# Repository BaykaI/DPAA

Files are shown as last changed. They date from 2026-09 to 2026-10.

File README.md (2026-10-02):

# DPAA — ЦАФАР, которую можно услышать

Проект демонстрации принципов **цифровой активной фазированной антенной решётки
(ЦАФАР)** в акустическом диапазоне: вместо антенн — динамики и микрофоны, вместо
СВЧ — звук 1.5–4 кГц, вместо осциллографа — уши зрителей.

Звук в ~875 000 раз медленнее радиоволн, поэтому решётка из восьми динамиков
с шагом 4 см геометрически эквивалентна решётке S-диапазона, а обычная
многоканальная звуковая карта оцифровывает сигнал прямо на «несущей» — то, о чём
мечтают разработчики настоящих ЦАФАР.

Подробная концепция, расчёты, сценарии и варианты железа: **[docs/concept.md](docs/concept.md)**.

**Железо** (16 элементов, ПЛИС ECP5 на модуле Colorlight i9, ≈ 630 $, с резервом ≈ 725 $ из 1000 $):
[архитектура](docs/hardware/architecture.md) · [что купить и заказать](docs/hardware/purchase.md) · [спецификация и бюджет](docs/hardware/bom.md) ·
[схемы плат](docs/hardware/schematics.md) · [распиновка](docs/hardware/pinout.md) ·
[схема соединений](docs/hardware/wiring.md) · [полная структурная схема](docs/img/full_diagram.svg) · [элемент: динамик + микрофон, 3D-модель](docs/hardware/mechanics.md) ·
[прошивка ПЛИС](gateware/README.md)

Структурная схема установки

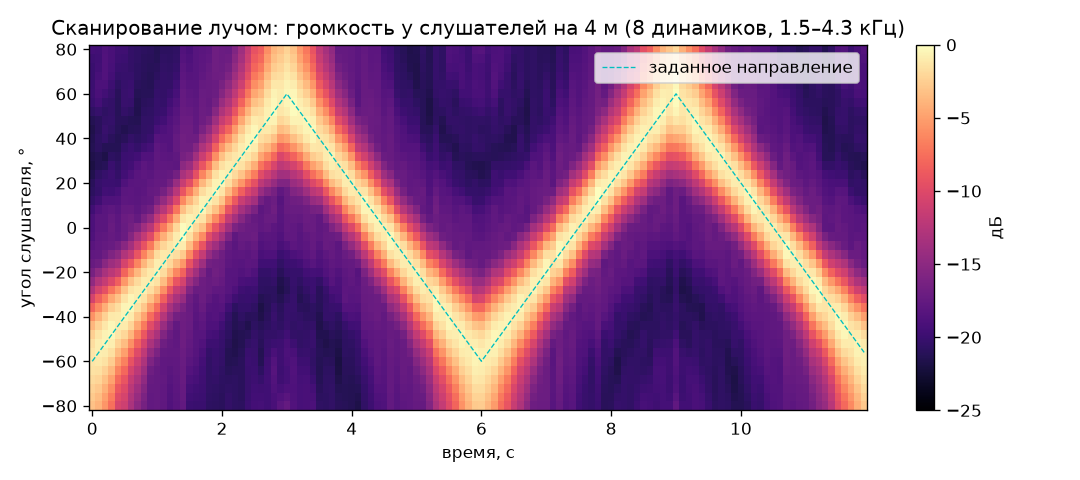
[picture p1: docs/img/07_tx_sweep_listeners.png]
Сканирование лучом


## Что уже есть

* `dpaa/` — небольшая библиотека моделирования:
  * `geometry.py` — решётки (линейные, плоские), направления, задержки фазирования;
  * `signals.py` — дробные задержки (БПФ и КИХ для реального времени), фазовращатель,
    тестовые сигналы;
  * `patterns.py` — диаграммы направленности, весовые окна, «косоглазие» луча, квантование;
  * `propagation.py` — распространение звука в свободном поле;
  * `transmit.py` — формирование лучей на передачу, многолучевость, сканирование, запись WAV;
  * `beamforming.py` — приём: задержка-сумма, MVDR (Кейпон), «акустическая камера».
* `scripts/`:
  * `design_calc.py` — таблицы параметров решётки;
  * `plot_patterns.py` — иллюстрации в `docs/img/`;
  * `make_tx_demo.py` — 8-канальные WAV для реальной решётки динамиков и
    **моно-WAV «виртуальных слушателей»** — можно послушать эффект в наушниках уже сейчас;
  * `demo_rx_sim.py` — приём двумя лучами и адаптивное подавление помехи.
* `dpaa/hw.py` — аппаратная модель: карта регистров, протокол UART, фиксированная точка,
  эталонная модель ядра ПЛИС (RTL сверяется с ней бит в бит).
* `gateware/` — прошивка ПЛИС на Verilog: I2S на 16 усилителей и 17 микрофонов,
  генераторы, цифровое диаграммообразование на передачу (2 луча) и приём (2 луча).
* `tools/dpaa_ctl.py` — управление с ноутбука: луч, сканирование, два луча, фокус,
  поэлементный тест, лучи приёма в наушники, уровни микрофонов.
* `software/DpaaControl/` — **пульт управления на C#** (.NET 8 + Avalonia, Windows/Linux/macOS):
  все сценарии `dpaa_ctl.py` с ползунками, план зала с лепестком звука, диаграмма
  направленности, уровни микрофонов, симулятор ПЛИС для работы без железа —
  [README](software/DpaaControl/README.md).
* `firmware/esp32/` — **прошивка Wi-Fi-пульта ESP32-S3**: своя сеть Wi-Fi, страница для планшета
  (луч «пальцем», маятник, два луча, прожектор, приём), автопилот для музея, служебная панель —
  [README](firmware/esp32/README.md).
* `tests/` — проверки физики и алгоритмов и RTL-тесты ПЛИС (`pytest`, нужен Icarus Verilog).

## Быстрый старт

```bash
pip install -r requirements.txt
python -m pytest -q                 # тесты
python scripts/design_calc.py       # расчёт параметров
python scripts/plot_patterns.py     # графики -> docs/img/
python scripts/make_tx_demo.py      # WAV -> out/tx/
python scripts/demo_rx_sim.py       # WAV -> out/rx/
```

Послушать без железа: `out/tx/listen_two_beams_-35deg.wav` и `..._+35deg.wav` —
что слышат два человека, стоящие по разные стороны от решётки, воспроизводящей
два луча одновременно; `out/tx/listen_prism_phase_*` — «звуковая призма»;
`out/rx/mic1.wav` vs `out/rx/mvdr_target.wav` — подавление помехи на приёме.

## Соглашения

Решётка лежит вдоль оси x и излучает вдоль +y. Угол отсчитывается от нормали,
положительные углы — вправо, если стоять за решёткой и смотреть в направлении
излучения. Канал 1 многоканального WAV — крайний левый элемент.

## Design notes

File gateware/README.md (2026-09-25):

# Прошивка ПЛИС (Lattice ECP5: Colorlight i9 или ULX3S)

| Файл | Назначение |
|---|---|
| `rtl/top_colorlight_i9.v` | верхний уровень Colorlight i9 (основная плата): PLL, UART к ESP32-S3 и ноутбуку |
| `rtl/top_ulx3s.v` | верхний уровень ULX3S (альтернатива) |
| `colorlight_i9_dpaa.lpf` | ограничения i9 — шаблон, заполнить выводы по распиновке платы расширения |
| `rtl/dpaa_core.v` | ядро: регистры, генераторы, ДОС передачи и приёма, I2S, измерители |
| `rtl/delay_sum_engine.v` | цифровое диаграммообразование: дробная задержка + вес + сумма |
| `rtl/sig_gen.v` | генератор: синус (DDS), шум, ЛЧМ, пачки, биквад, огибающая |
| `rtl/i2s_clkgen.v`, `i2s_tx.v`, `i2s_rx.v` | общий такт и многоканальный I2S |
| `rtl/uart_rx.v`, `uart_tx.v`, `uart_cmd.v` | команды управления |
| `rtl/*.hex` | таблицы (генерируются `gen_mem.py` из `dpaa/hw.py`) |
| `tb/` | тестбенчи Icarus Verilog; запускаются из `tests/test_gateware.py` |

```bash
sudo apt install yosys nextpnr-ecp5 fpga-trellis iverilog openfpgaloader
make sim                 # RTL-тесты: ядро сверяется с Python-моделью бит в бит
make check               # синтез + разводка без привязки выводов (Colorlight i9): ресурсы и Fmax
make                     # битстрим для i9 (нужен заполненный colorlight_i9_dpaa.lpf)
make prog                # загрузка через DAPLink платы расширения
make BOARD=ulx3s ...     # то же для ULX3S (нужен официальный ulx3s_v20.lpf)
```

Проверено (`./check_all.sh` — проверочная разводка для всех плат сразу):
Colorlight i9 (45F) — 23 % LUT, 54 МГц; Colorlight i5 (25F) — 42 % LUT, 56 МГц;
ULX3S (85F) — 12 % LUT, 55 МГц при рабочих 50 МГц.

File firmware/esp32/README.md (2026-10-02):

# Прошивка Wi-Fi-пульта (ESP32-S3-DevKitC-1)

ESP32 раздаёт свою сеть Wi-Fi, показывает посетителям страницу управления на планшете и
передаёт команды в ПЛИС по UART. Ноутбук для работы экспоната не нужен.

```
планшет ── Wi-Fi «DPAA» ──> ESP32-S3: страница + логика пульта ── UART1, 1 Мбит/с ──> ПЛИС
```

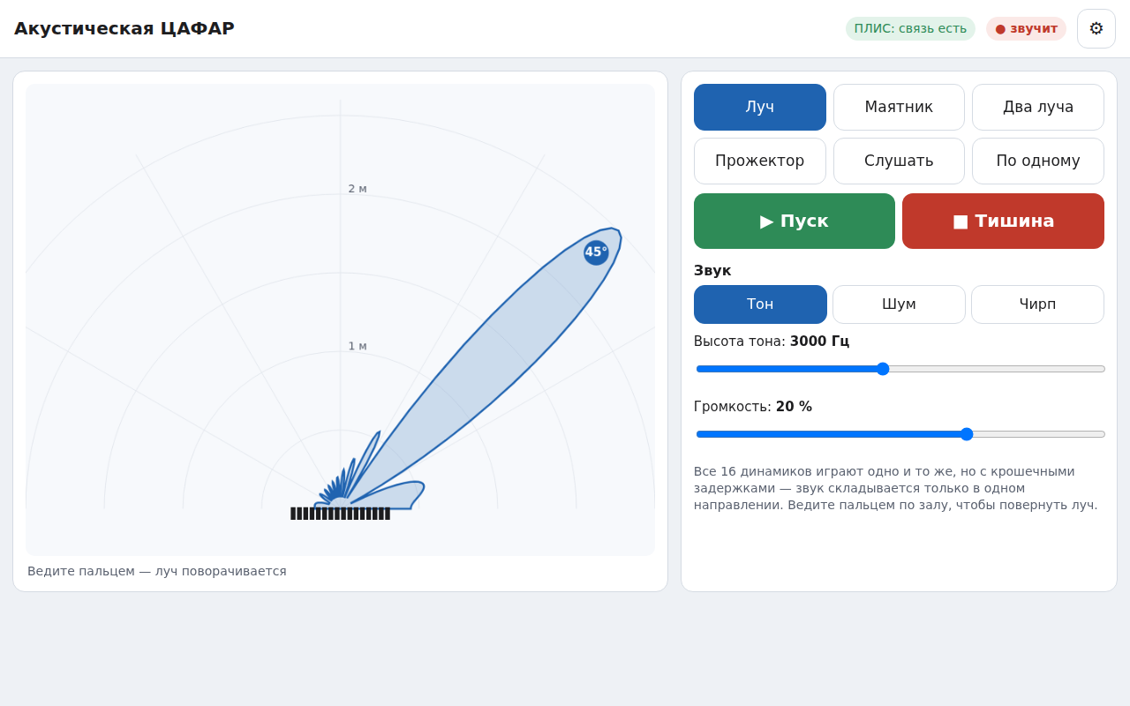
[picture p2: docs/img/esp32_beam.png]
Страница пульта: луч на +45°


## Что умеет

* **Шесть сценариев** для посетителей:
  * **Луч** — ведёшь пальцем по плану зала, и луч поворачивается;
  * **Маятник** — сканирование;
  * **Два луча** — синий и красный, оба перетаскиваются;
  * **Прожектор** — коснись точки, и звук сфокусируется в ней;
  * **Слушать** — два луча приёма в наушники;
  * **По одному** — проверка элементов.
* **Звук:** тон (высота регулируется), полосовой шум или ЛЧМ-пачки («чирп»).
* **Тишина** — большая красная кнопка. После включения питания решётка молчит.
* **Автопилот для музея.** Если экспонатом не пользуются 90 с, решётка сама показывает
  четыре номера по 15 с: маятник тоном, два луча, «гуляющий» прожектор, маятник шумом.
  Громкость автопилота не выше 20 %. Первое касание экрана возвращает управление
  посетителю. Поэлементный тест и приём автопилот не прерывает.
* **Служебная панель** (кнопка ⚙):
  * амплитудное распределение: Тейлор, Чебышёв, Ханн, отключение элементов, свои веса;
  * диапазон и период маятника;
  * потолок громкости для посетителей (по умолчанию 30 %, максимум 50 %);
  * автопилот: включение и задержка;
  * уровни 16 микрофонов и зонда.
* Настройки хранятся в энергонезависимой памяти и переживают выключение.

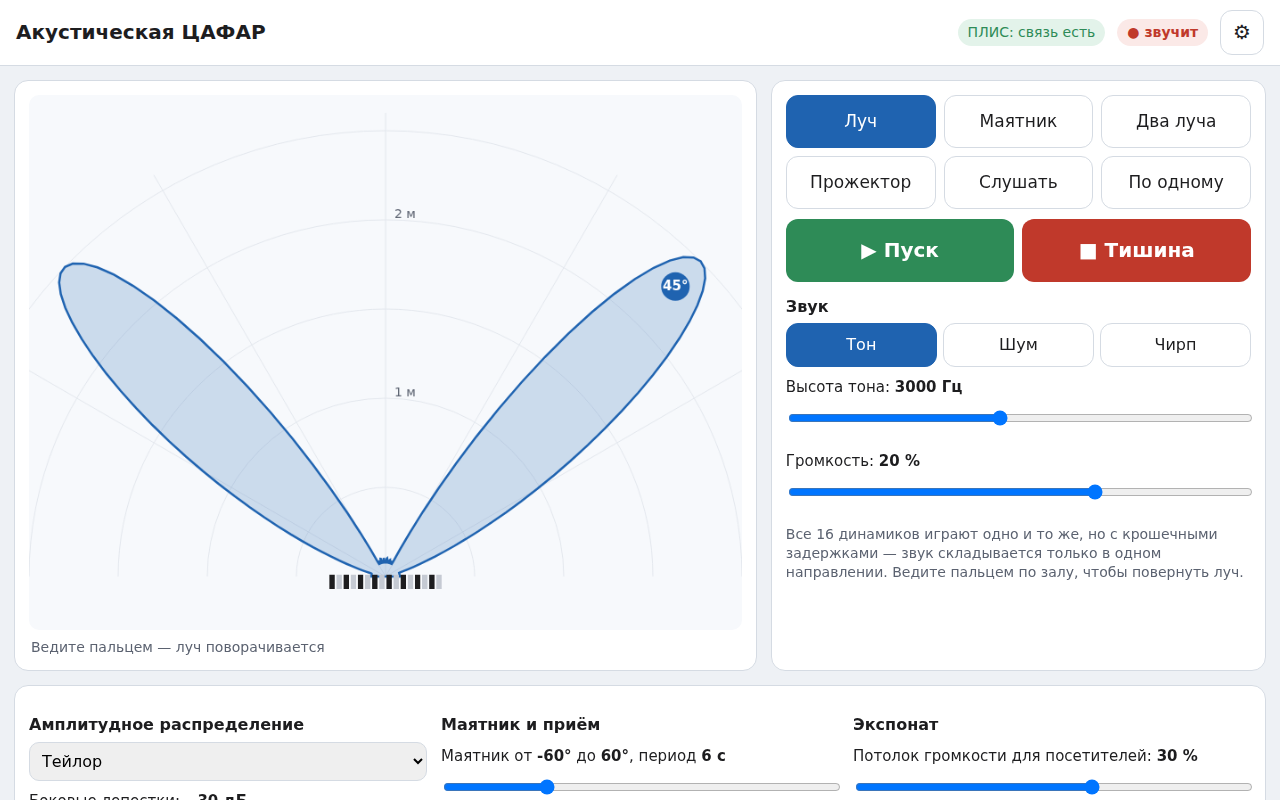
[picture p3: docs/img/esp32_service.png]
Служебная панель: окно Тейлора и прореживание «через один» — виден дифракционный лепесток


На странице рисуется лепесток звука. Задержки при этом квантуются до 1/32 отсчёта, как в
регистрах ПЛИС, а веса берутся фактические — их присылает ESP32.

## Подключение

К разъёму J25 распределительной платы (см. [wiring.md](../../docs/hardware/wiring.md)) тремя
проводами Dupont:

| ESP32-S3-DevKitC-1 | J25 | ПЛИС |
|---|---|---|
| GPIO17 (TX UART1) | 2 | `esp_rx` |
| GPIO18 (RX UART1) | 1 | `esp_tx` |
| GND | 3 | земля |

Питание ESP32 — от USB-зарядника G2 (разъём «UART» или «USB» на плате).

## Сборка и прошивка

Нужен [PlatformIO](https://platformio.org/): расширение для VS Code или командная строка
(`pip install platformio`). Внешних библиотек нет — только то, что входит в Arduino-ESP32.

```bash
cd firmware/esp32
pio run                  # сборка (страница web/index.html упаковывается в прошивку сама)
pio run -t upload        # прошивка: кабель USB в разъём «UART» платы
pio device monitor       # журнал, 115200 бод
```

Готовые файлы прошивки собирает GitHub Actions: артефакт `dpaa-esp32-firmware` в задаче
**CI → «Прошивка ESP32-S3»**. Их можно записать без PlatformIO:

```bash
esptool.py --chip esp32s3 erase_flash
esptool.py --chip esp32s3 write_flash 0x0 bootloader.bin 0x8000 partitions.bin 0x10000 firmware.bin
```

## Первое включение

1. Включить ESP32 и подключить планшет к сети **`DPAA`**, пароль **`dpaa2026`**.
2. Страница пульта откроется сама. Если не открылась — адрес `http://192.168.4.1/`
   или `http://dpaa.local/`.
3. Индикатор «ПЛИС: связь есть» — ПЛИС прошита и UART подключён верно.
4. Сменить имя и пароль сети: `http://192.168.4.1/api/wifi?ssid=Имя&pass=НовыйПароль`
   (пароль от 8 символов), после этого ESP32 перезагрузится.

Ноутбук с `tools/dpaa_ctl.py` или C#-пультом можно подключать одновременно: у ПЛИС два
порта команд, а ESP32 сам отбрасывает ответы, адресованные ноутбуку.

## Устройство

```
firmware/esp32/
├── platformio.ini
├── src/main.cpp             — «железо»: UART1, Wi-Fi, веб-сервер, DNS, настройки во флеше
├── src/web_page.h           — страница в gzip (генерируется tools/embed_web.py)
├── web/index.html           — страница пульта (HTML + JS, без внешних файлов)
├── lib/dpaa/src/
│   ├── dpaa_core.*          — протокол, регистры, окна, лучи, сценарии (перенос dpaa/hw.py и dpaa_ctl.py)
│   └── controller.*         — веб-API, маятник, поэлементный тест, автопилот, опрос уровней
├── tools/embed_web.py
└── test/
    ├── host/dpaa_host.cpp   — та же логика на компьютере + симулятор ПЛИС
    ├── web_mock.py          — «ESP32 на компьютере»: страница + логика + симулятор
    └── stubs/               — заглушки Arduino для проверки компиляции main.cpp
```

### Веб-API

Запросы GET, ответ — JSON состояния (режим, параметры, связь с ПЛИС, уровни микрофонов):

| Запрос | Что делает |
|---|---|
| `/api/state` | только состояние |
| `/api/set?mode=beam&az=30&run=1` | сменить параметры. `mode`: `beam`, `sweep`, `focus`, `two`, `listen`, `elements`; `run=1` — пуск, `run=0` — тишина |
| `/api/stop` | тишина |
| `/api/wifi?ssid=…&pass=…` | имя и пароль сети, затем перезагрузка |

Параметры `/api/set`:

| Группа | Параметры |
|---|---|
| сигнал | `src` (0 — тон, 1 — шум, 2 — ЛЧМ), `tone`, `amp` |
| луч | `az` |
| маятник | `sf`, `st`, `sp` |
| прожектор | `fx`, `fy` |
| два луча | `az1`, `az2`, `t1`, `s2`, `t2` |
| приём | `left`, `right` |
| по одному | `et`, `dw` |
| распределение | `taper` (0–3), `sll`, `off` (маска выключенных элементов), `cw`, `w` (16 весов) |
| экспонат | `maxamp`, `demo`, `idle` |

### Проверка без ESP32

```bash
python -m pytest tests/test_esp32.py tests/test_esp32_web.py
python firmware/esp32/test/web_mock.py      # пульт в браузере компьютера: http://localhost:8080/
```

* **Кадры для ПЛИС** сверяются с Python-моделью бит в бит: эталоны `golden.json` (общие с C#-пультом)
  и 300 случайных конфигураций лучей, фокуса и приёма с разными распределениями.
* **Контроллер** проверяется отдельно:
  * живое обновление не чаще 25 раз в секунду;
  * маятник обновляется 50 раз в секунду;
  * обход элементов;
  * автопилот включается через заданное время, и касание экрана возвращает управление;
  * ограничение громкости и сообщения об ошибках.
* **Страница** открывается в Chromium (Playwright), где нажимаются кнопки и «водится пальцем».
  Проверяется, что кадры действительно уходят в симулятор ПЛИС.

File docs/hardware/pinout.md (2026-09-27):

# Распиновка

## Основная плата: Colorlight i9 + плата расширения

Порты верхнего уровня — `gateware/rtl/top_colorlight_i9.v`, ограничения —
`gateware/colorlight_i9_dpaa.lpf`. В шаблоне все выводы стоят как `SITE "???"`:
их нужно заполнить по распиновке платы расширения i9 v7.2 (таблица PMOD P1–P6 из
документации платы у продавца или в проектах сообщества Colorlight i5/i9). Пока
остаётся хоть одна заглушка, `make` откажется собирать битстрим — это защита от
неверной распиновки.

| Порт | Направление | Сигнал | Разъём (контакты — в [wiring.md](wiring.md)) |
|---|---|---|---|
| `clk25` | вход | генератор 25 МГц модуля i9 | (на модуле) |
| `led` | выход | «сердцебиение» ≈ 1.5 Гц | (светодиод модуля) |
| `bclk`, `lrclk`, `mon_sd` | выход | такты I2S, ЦАП наушников | P1 |
| `esp_tx`, `esp_rx` | выход / вход | UART к ESP32-S3 (1 Мбод) | P1 |
| `txd[0..15]` | выход | данные усилителей 1–16 | P2, P3 |
| `rxd[0..15]` | вход | микрофоны 1–16 | P4, P5 |
| `rxd[16]` | вход | калибровочный зонд | P6 |
| `usb_tx`, `usb_rx` | выход / вход | UART к ноутбуку (USB-UART DAPLink или адаптер CP2102 на J28) | P1 или линии DAPLink |
| `btn_test` | вход | кнопка SW1 «тестовый тон» на распределительной плате | P1 |

Проверьте по документации платы, выведен ли USB-UART отладчика DAPLink на выводы ПЛИС.
Если нет, подключите к `usb_tx`/`usb_rx` копеечный адаптер CP2102/CH340 (3.3 В).
Загрузка прошивки идёт через DAPLink: `make prog` (`openFPGALoader -c cmsisdap`).

ESP32-S3 соединяется с ПЛИС тремя проводами: GPIO TX → `esp_rx`, GPIO RX ← `esp_tx`, GND.
Питание ESP32 — от своего USB. Прошивка ESP32 не зависит от ПЛИС: в отличие от ULX3S,
её не нужно перепрошивать через ПЛИС.

## Альтернатива: ULX3S

### Порты ПЛИС (ULX3S)

Имена портов совпадают с официальным файлом ограничений ULX3S, поэтому номера
выводов кристалла берутся оттуда, а не придумываются: скачайте `ulx3s_v20.lpf` из
документации ULX3S (репозиторий платы, каталог с файлами ограничений) и положите в
`gateware/`. `make` объединит его с `ulx3s_dpaa_io.lpf` (настройки буферов).

| Порт | Направление | Сигнал | Куда |
|---|---|---|---|
| `clk_25mhz` | вход | генератор 25 МГц | PLL → 50 МГц |
| `gp[0]` | выход | BCLK 3.125 МГц | U1, U2, U9 распред. платы |
| `gp[1]` | выход | LRCLK 48.828 кГц | U3, U4, U9 |
| `gp[2]` … `gp[17]` | выход | TXD0 … TXD15 | U5, U6 → элементы 1–16 |
| `gp[18]` | выход | MON_SD | ЦАП наушников PCM5102A |
| `gn[0]` … `gn[15]` | вход | MIC0 … MIC15 | U7, U8 ← элементы 1–16 |
| `gn[16]` | вход | CAL | калибровочный зонд |
| `gp[19..27]`, `gn[17..27]` | — | свободны (Z) | резерв: вторая решётка, датчики |
| `ftdi_txd` / `ftdi_rxd` | вход / выход | UART к ноутбуку | USB-разъём US1 ULX3S |
| `wifi_txd` / `wifi_rxd` | вход / выход | UART к ESP32 | встроенный ESP32 |
| `wifi_en`, `wifi_gpio0` | выход | = 1 | ESP32 включён, обычная загрузка |
| `btn[1]` (FIRE1) | вход | тестовый тон | пока нажата — тон 3 кГц по нормали |
| `led[7:0]` | выход | индикация | 0 — «сердцебиение», 1 — излучение, 2 — приём, 3 — команды UART, 4–7 — уровень микрофона 1 |

Перед первым включением сверьте по схеме своей ревизии ULX3S:
* на какие контакты разъёмов J1/J2 выведены gp/gn 0–18 (нумерация на шелкографии платы);
* активный уровень кнопки FIRE1 (в проекте — активная «1»);
* что gp/gn 0–18 не заняты перемычками/периферией в вашей ревизии.

При другой раскладке правится только `gateware/rtl/top_ulx3s.v` (назначение сигналов
на gp/gn) и таблица в [schematics.md](schematics.md).

**ESP32 и прошивка ПЛИС.** Пока в ПЛИС загружен этот проект, UART ESP32 занят
командами, поэтому саму ESP32 прошивайте, предварительно загрузив в ПЛИС стандартный
«passthru»-битстрим ULX3S (обычная процедура для этой платы), затем вернитесь к
`make prog`.

## Разъём элемента Jn на распределительной плате (штыревой 2×6) и провода Dupont

| Контакт | Сигнал | → модуль | Контакт | Сигнал | → модуль |
|---|---|---|---|---|---|
| 1 | +5 В | MAX98357A VIN | 2 | +3.3 В | ICS-43434 VDD |
| 3 | GND | MAX98357A GND | 4 | GND | ICS-43434 GND |
| 5 | BCLK | MAX98357A BCLK | 6 | BCLK | ICS-43434 SCK |
| 7 | LRCLK | MAX98357A LRC | 8 | LRCLK | ICS-43434 WS |
| 9 | TXD | MAX98357A DIN | 10 | RXD | ICS-43434 SD |
| 11 | GND (резерв) | — | 12 | GND | ICS-43434 L/R |

Нечётный ряд — 5 проводов к усилителю, чётный — 6 проводов к микрофону. Провода Dupont
«мама–мама» 30–40 см; подключать по надписям на модулях.

Номер элемента = номер разъёма J1…J16 = позиция в решётке слева направо, если
стоять за решёткой лицом по направлению излучения (положительные углы — вправо).

## Кабель калибровочного зонда (RJ45, T568B)

| Пара | Контакты | Сигнал | → модуль ICS-43434 зонда |
|---|---|---|---|
| 1 | 1–2 | BCLK / GND | SCK / GND |
| 2 | 3–6 | LRCLK / GND | WS / L/R |
| 3 | 4–5 | +3.3 В / +3.3 В | VDD |
| 4 | 7–8 | SD / GND | SD / — |

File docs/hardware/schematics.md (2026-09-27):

# Схемы (теоретическая проработка)

**Принцип: максимум готовых модулей, минимум ручного монтажа.** Своя плата в установке
одна — **распределительная (A3)**, и её собирает фабрика (SMT + выводной монтаж). Всё
остальное — готовые модули, которые соединяются проводами Dupont «мама–мама»
и готовыми шлейфами: без обжима и без пайки. Паять вручную остаётся только штыревые
гребёнки модулей, если продавец присылает их отдельно, и провода динамиков.

Механика элемента — [mechanics.md](mechanics.md), соединения устройств —
[wiring.md](wiring.md). Все логические сигналы — LVCMOS 3.3 В.

---

## 1. Элемент решётки (16 шт.) — только готовые модули

```
   A3: разъём Jn (2×6)          провода Dupont F–F, 30–40 см
   нечётный ряд  ── 1 +5V  ──────────────► VIN  ┐
                 ── 3 GND  ──────────────► GND  │ A6.1 модуль MAX98357A
                 ── 5 BCLK ──────────────► BCLK │ (ЦАП + усилитель класса D)
                 ── 7 LRCLK ─────────────► LRC  │ GAIN, SD — не подключать
                 ── 9 TXD  ──────────────► DIN  ┘ OUT+/OUT− → BA1 динамик
   чётный ряд    ── 2 +3.3V ─────────────► VDD  ┐
                 ── 4 GND  ──────────────► GND  │ A6.2 модуль ICS-43434
                 ── 6 BCLK ──────────────► SCK  │ (микрофон с АЦП 24 бит)
                 ── 8 LRCLK ─────────────► WS   │
                 ── 10 RXD ◄───────────── SD   │
                 ── 12 GND ──────────────► L/R  ┘ (левый слот)
                    11 — GND, резерв
```

| Модуль | Вывод | Откуда | Примечание |
|---|---|---|---|
| A6.1 MAX98357A | VIN | Jn.1 (+5 В) | ток до ~0.5 А в пиках — один провод Dupont достаточен |
| | GND | Jn.3 | |
| | BCLK | Jn.5 | свой выход буфера на A3 |
| | LRC | Jn.7 | свой выход буфера на A3 |
| | DIN | Jn.9 | данные элемента n |
| | GAIN | не подключать | усиление 9 дБ; громкость задаётся цифрой в ПЛИС |
| | SD | не подключать | модуль включён; режим L/R не важен — в оба слота идёт одно и то же |
| | OUT+, OUT− | динамик BA1 | 2 провода (у модуля Adafruit — винтовая колодка) |
| A6.2 ICS-43434 | VDD | Jn.2 (+3.3 В) | чистое 3.3 В с отдельного стабилизатора U21 на A3 |
| | GND | Jn.4 | |
| | SCK | Jn.6 | свой выход буфера на A3 |
| | WS | Jn.8 | свой выход буфера на A3 |
| | SD | Jn.10 | на A3: 100 кОм к земле, буфер к ПЛИС |
| | L/R | Jn.12 (GND) | левый слот |

Порядок выводов на гребёнках модулей у разных продавцов разный — подключайте **по
надписям на модуле**, а не по положению штырьков.

---

## 2. Распределительная плата A3 (единственная своя плата, собирается фабрикой)

Задачи: размножить такты (по отдельному выходу буфера на каждую нагрузку), буферизовать
все линии (защита выводов ПЛИС), раздать 5 В с предохранителями и чистое 3.3 В
микрофонам, вывести два луча приёма в наушники.

```
 Плата ПЛИС: PMOD P1–P6 → J19–J24 (шлейфы W1–W6)
 BCLK ──[U1–U4 74LVC244]── 32 × 33 Ом ──► Jn.5 (усилители), Jn.6 (микрофоны)
 LRCLK ─[U5–U8 74LVC244]── 32 × 33 Ом ──► Jn.7, Jn.8
 TXD0–15 ─[U9, U10]─────── 16 × 33 Ом ──► Jn.9
 MIC0–15 ◄─33 Ом─[U11, U12]◄─ 100k↓ ──── Jn.10
 MON_SD, BCLK, LRCLK ─[U13]──► U31 PCM5102A ─► U32 TDA1308 ─► J26, J27 (наушники)
 BCLK, LRCLK ─[U13]──► J17 RJ45 (зонд);  CAL ◄─[U13]◄── J17
 ESP_TX/RX ↔ 100 Ом ↔ J25;  USB_TX/RX ↔ 100 Ом ↔ J28;  SW1 → BTN_TEST

 +5V (J18) → Q1 → D1 TVS → C 1000 мкФ → F1–F4 (PTC 1.5 А, по 4 элемента) → Jn.1
           → U20 AP2112K-3.3 → 3V3_LOGIC (буферы U1–U13, U31)
           → FB1 → U21 AP2112K-3.3 → 3V3_MIC → Jn.2 (16 микрофонов), J17 (зонд)
           → U32 TDA1308 (5 В)
```

### Разъём элемента Jn (J1–J16): штыревой 2×6, шаг 2.54 мм

| Контакт | Цепь | Контакт | Цепь |
|---|---|---|---|
| 1 | +5 В (через F1–F4) | 2 | +3.3 В (3V3_MIC) |
| 3 | GND | 4 | GND |
| 5 | BCLK усилителя | 6 | BCLK (SCK) микрофона |
| 7 | LRCLK усилителя | 8 | LRCLK (WS) микрофона |
| 9 | TXD n | 10 | RXD n (SD микрофона) |
| 11 | GND (резерв) | 12 | GND (для L/R микрофона) |

Нечётный ряд — к усилителю, чётный — к микрофону: провода из одного ряда идут к одному
модулю, перепутать трудно.

### Буферы

| Буфер | Входы | Выходы (каждый через 33 Ом) |
|---|---|---|
| U1, U2 | BCLK | Jn.5, n = 1…16 |
| U3, U4 | BCLK | Jn.6 |
| U5, U6 | LRCLK | Jn.7 |
| U7, U8 | LRCLK | Jn.8 |
| U9, U10 | TXD0–15 | Jn.9 |
| U11, U12 | Jn.10 (+100 кОм к GND) | MIC0–15 → ПЛИС |
| U13 | BCLK, LRCLK, MON_SD, CAL | U31 (BCK, LRCK, DIN), J17 (BCLK, LRCLK), CAL → ПЛИС |

Все 74LVC244: VCC = 3V3_LOGIC, ~OE = GND, 100 нФ у каждого корпуса; входы допускают 5 В.

### Монитор наушников (на плате, без отдельных модулей)

| Поз. | Тип | Подключение |
|---|---|---|
| U31 | PCM5102A (TSSOP-20) | BCK, LRCK, DIN — от U13; SCK — GND (без MCLK, внутренний PLL); FMT — GND (I2S); XSMT — 3.3 В; FLT, DEMP — GND; обвязка LDO и накачки заряда — по типовой схеме даташита |
| U32 | TDA1308 (SO-8), питание 5 В | вход — LOUT/ROUT U31 через 1 мкФ; смещение — делитель 2 × 10 кОм + 10 мкФ; выходы — через 220 мкФ на J26, J27 |
| J26, J27 | гнёзда 3.5 мм, стерео | параллельно: левое ухо — луч приёма 0, правое — луч 1 |

**Регулятор громкости не нужен:** громкость лучей приёма задаётся весами в ПЛИС
(`dpaa_ctl.py`, пульт на планшете). TDA1308 нужен только как «силовой» каскад:
выход PCM5102A — линейный, он рассчитан на нагрузку от 1 кОм, а у наушников 16–32 Ом.

### Питание

| Поз. | Тип | Назначение |
|---|---|---|
| J18 | гнездо 5.5/2.1 мм | вход 5 В от G1 |
| Q1 | P-MOSFET ≥ 8 А, ≤ 20 мОм (AO4407A) | защита от переполюсовки |
| D1 | SMBJ5.0A | защита от выбросов |
| C10 | 1000 мкФ 10 В + 10 мкФ | накопитель |
| F1–F4 | PTC 1.5 А (1812) | по одному на группу из 4 элементов |
| U20 | AP2112K-3.3 | 3.3 В логики |
| U21 + FB1 | AP2112K-3.3 + феррит 600 Ом | отдельное чистое 3.3 В микрофонам (помехи усилителей класса D не попадают в приём) |
| LED1, LED2 | + 1 кОм | индикация 5 В и 3.3 В |

### Прочие разъёмы

J17 — RJ45 (зонд), J19–J24 — штыревые 2×6 (PMOD), J25, J28 — штыревые 1×3 (ESP32 и
резервный UART), SW1 — кнопка «тест». Раскладка контактов — [wiring.md](wiring.md).

---

## 3. Калибровочный зонд — готовые модули

| Поз. | Что | Подключение |
|---|---|---|
| — | готовая плата-переходник RJ45 с винтовыми клеммами | кабель CAT5 3 м от J17 |
| A22 | модуль ICS-43434 (такой же, как в элементах) | VDD, GND, SCK, WS, SD, L/R — провода Dupont в клеммы переходника |

Раскладка кабеля (T568B): пара 1–2 — BCLK/GND, 3–6 — LRCLK/GND, 4–5 — 3.3 В/3.3 В,
7–8 — SD/GND. Буферов на стороне зонда нет; если на 3 м появятся сбои, укоротите кабель
до 1.5–2 м.

---

## 4. Риски упрощённой схемы и что проверить первым делом

* **Такты по проводам Dupont без буфера на элементе.** На 3.125 МГц при длине до 40 см
  это обычно работает, но фронты могут «звенеть». Проверка: один элемент на самом
  длинном проводе, команды `peaks` и `elements`. Если есть сбои — укоротить провода,
  держать жгут элемента вместе (земли рядом с тактами) или поставить ферритовую бусину
  на провод BCLK.
* **Питание 5 В по одному проводу Dupont** — рассчитано на умеренную громкость
  (≤ 0.5 Вт на элемент); на максимальной громкости провод греется.
* Порядок выводов модулей — по надписям на плате модуля.
* Ключи шлейфов PMOD — одинаковая ориентация на обоих концах.

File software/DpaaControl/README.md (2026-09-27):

# DpaaControl — пульт управления акустической ЦАФАР (C#)

Настольное приложение для ноутбука: подключается к плате ПЛИС по USB-UART (1 Мбит/с)
и управляет решёткой. Работает на Windows 10/11, Linux и macOS (.NET 8 + Avalonia).
Без железа можно работать с **симулятором** — он отвечает как ПЛИС и изображает уровни
микрофонов, так что демонстрацию можно отрепетировать заранее.

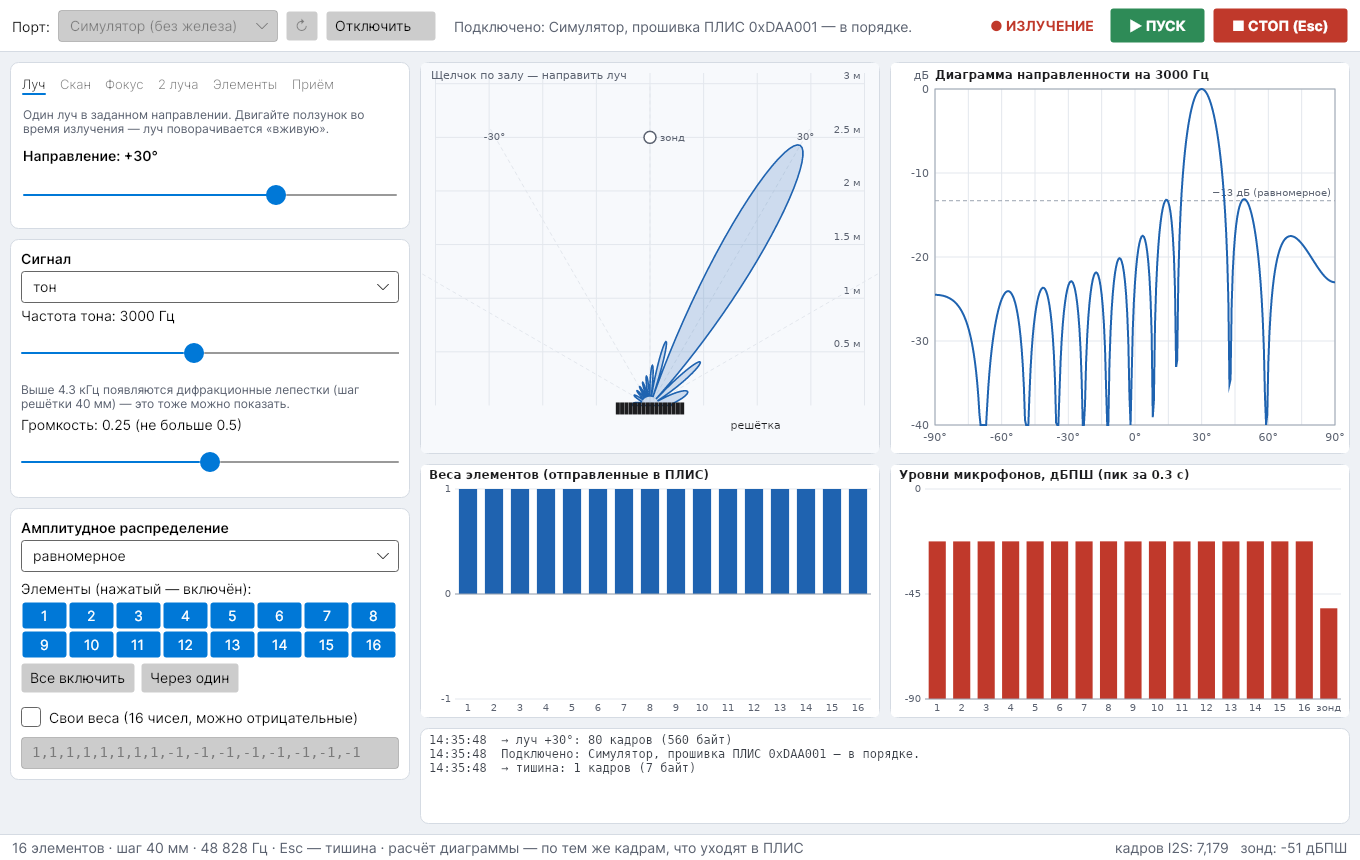
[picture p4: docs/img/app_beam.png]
Луч на +30°


## Что умеет

| Вкладка | Что происходит | Аналог в `tools/dpaa_ctl.py` |
|---|---|---|
| **Луч** | луч в заданном направлении; ползунок или щелчок по плану зала поворачивает его «вживую» | `beam` |
| **Скан** | луч качается маятником между двумя углами | `sweep` |
| **Фокус** | фокусировка в точку ближней зоны (щелчок по плану) | `focus` |
| **2 луча** | два независимых луча с разными сигналами | `two-beams` |
| **Элементы** | элементы звучат по очереди — проверка монтажа | `elements` |
| **Приём** | два луча приёма в наушники: левое и правое ухо | `listen` |

Для всех вкладок, кроме «Элементов»:

* **сигнал**: тон 500–6000 Гц, полосовой шум 1.5–4.3 кГц или ЛЧМ-пачки 2→4 кГц;
  громкость ограничена половиной шкалы (как в `dpaa_ctl.py`);
* **амплитудное распределение**: равномерное, Тейлор, Чебышёв, Ханн с заданным уровнем
  боковых лепестков; выключение отдельных элементов (например, «через один» — появляются
  дифракционные лепестки); свои веса, в том числе отрицательные (разностная диаграмма).

Справа — план зала сверху с «лепестком» звука, диаграмма направленности в дБ, веса
элементов и уровни 16 микрофонов и калибровочного зонда (опрос каждые 0.3 с).
**Диаграмма считается по тем же кадрам, что уходят в ПЛИС**: по квантованным регистрам
задержки (шаг 1/32 отсчёта) и веса — на экране ровно то, что излучит установка.

Клавиша **Esc** или кнопка «СТОП» — тишина. При закрытии окна установка тоже замолкает.

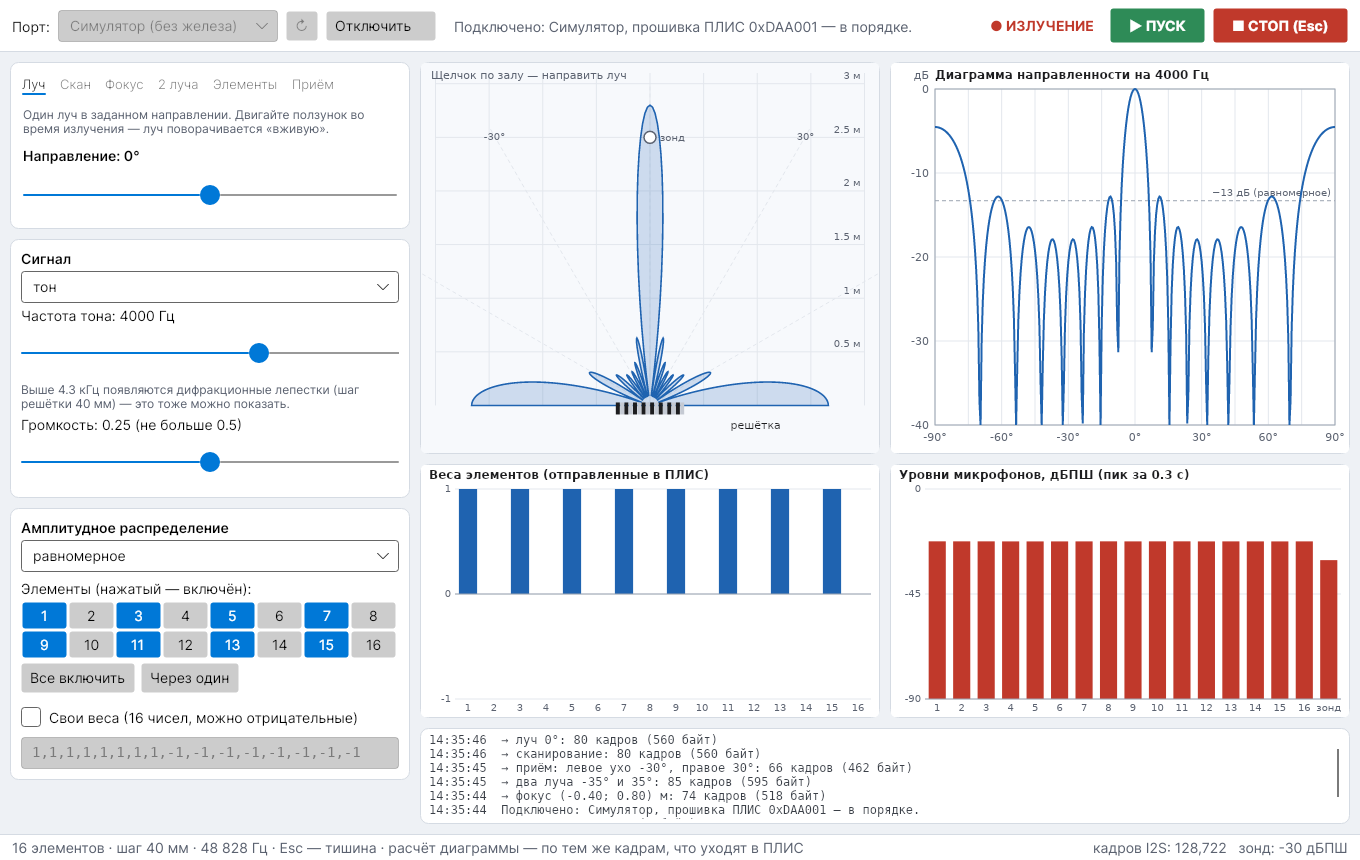
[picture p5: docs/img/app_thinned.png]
Прореживание «через один» на 4 кГц: дифракционные лепестки


## Сборка и запуск

Нужен [.NET SDK 8](https://dotnet.microsoft.com/download) или новее (Visual Studio 2022/2026,
Rider или просто командная строка).

```bash
cd software/DpaaControl
dotnet run --project src/Dpaa.App          # запуск
dotnet test                                # тесты (25 шт.)
```

Один `.exe` для ноутбука экспоната (устанавливать .NET на нём не нужно):

```bash
dotnet publish src/Dpaa.App -c Release -r win-x64 --self-contained \
    -p:PublishSingleFile=true -p:IncludeNativeLibrariesForSelfExtract=true -o publish
```

Получится `publish/DpaaControl.exe` (≈ 90 МБ). Для Linux — `-r linux-x64`, для Mac —
`-r osx-arm64`. В Linux пользователю нужен доступ к порту: `sudo usermod -aG dialout $USER`.

Порт: в Windows — `COM…` отладчика DAPLink или адаптера CP2102/CH340 (см.
[pinout.md](../../docs/hardware/pinout.md)); в списке первым идёт «Симулятор (без железа)».

## Устройство

```
DpaaControl.sln
├── src/Dpaa.Core        — без интерфейса, можно использовать отдельно
│   ├── Hw.cs            — константы и карта регистров (как dpaa/hw.py)
│   ├── Protocol.cs      — кадры UART: A5 A1 A0 D2 D1 D0 CHK, ответ 5A …
│   ├── Fixed.cs         — форматы регистров: задержка, вес Q2.16, частота, биквад
│   ├── Geometry.cs      — положения динамиков и микрофонов, задержки луча и фокуса
│   ├── Tapers.cs        — окна Тейлора, Чебышёва, Ханна; Distribution (--taper/--off/--weights)
│   ├── Commands.cs      — таблицы лучей и генераторы (tx/rx_beam_commands, gen_commands)
│   ├── Scenarios.cs     — сценарии, кадр в кадр как у tools/dpaa_ctl.py
│   ├── RegisterFile.cs  — образ регистров из отправленных кадров
│   ├── Pattern.cs       — диаграмма направленности по регистрам (дальняя и ближняя зона)
│   └── Links.cs         — SerialLink (порт), SimulatedLink (симулятор)
├── src/Dpaa.App         — окно на Avalonia (MainWindow, MainViewModel, Controls/)
└── tests
    ├── Dpaa.Core.Tests  — сверка с Python бит в бит (golden.json) + физика
    └── Dpaa.App.Tests   — окно без экрана: сценарии на симуляторе, снимки окна
```

**Совместимость с прошивкой.** `golden.json` посчитан Python-моделью
(`python scripts/make_csharp_golden.py`) — той же, с которой сверяется RTL ПЛИС. Тесты
требуют совпадения кадров байт в байт: протокол, приращения фазы, коэффициенты фильтра шума,
окна, задержки лучей и фокуса, генераторы и все сценарии `dpaa_ctl.py`. Если меняется
`dpaa/hw.py` или прошивка, перегенерируйте эталоны и прогоните `dotnet test`.

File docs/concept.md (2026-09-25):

# Акустическая ЦАФАР: концепция

> Цель — показать принципы работы цифровой активной фазированной антенной решётки
> (ЦАФАР) так, чтобы их мог **услышать и увидеть** любой человек без радиотехнического
> образования и без измерительной аппаратуры.

## 1. Почему звук — идеальный «тренажёр» для ЦАФАР

**Физика одна и та же.** Интерференция, фазирование, дифракционные лепестки, ближняя и
дальняя зоны, ширина луча ~ λ/D — всё это свойства волнового уравнения, а не радио.
Важна не частота, а **длина волны относительно размеров решётки**.

**Та же длина волны — в миллион раз медленнее.** Звук распространяется примерно в
875 000 раз медленнее радиоволн, поэтому решётка из динамиков с шагом в несколько
сантиметров «работает» на частотах в единицы килогерц:

| Диапазон РЛС | f радио | λ | f звука с той же λ |
|---|---|---|---|
| L | 1.3 ГГц | 23.1 см | 1486 Гц |
| S | 3 ГГц | 10.0 см | 3430 Гц |
| C | 5.5 ГГц | 5.5 см | 6288 Гц |
| X | 10 ГГц | 3.0 см | 11433 Гц |

То есть акустическая решётка на 3–4 кГц — это геометрически точная модель решётки
S-диапазона, только «замедленная».

**Главный подарок: прямая оцифровка на несущей.** В настоящей ЦАФАР самое дорогое и
сложное — приёмопередающий модуль (ППМ) и АЦП/ЦАП в каждом канале, по возможности
ближе к антенне. В акустике обычный звуковой АЦП/ЦАП на 48 кГц оцифровывает сигнал
**прямо на несущей**, без гетеродинов и квадратурных преобразователей. Многоканальная
звуковая карта — это готовая «цифровая часть» ЦАФАР за копейки. Всё диаграммообразование
делается в компьютере, как и в настоящей ЦАФАР.

**Детектор — ухо, сканер — ноги.** Зритель, проходя вдоль решётки, буквально
«снимает» диаграмму направленности своими ушами: где громко — там луч.

### Соответствие понятий

| ЦАФАР (радио) | Акустическая модель |
|---|---|
| Излучающий элемент | Небольшой динамик (Ø 30–40 мм) |
| Приёмный элемент | Микрофон (электретный или цифровой MEMS) |
| ППМ (приёмопередающий модуль) | Канал: ЦАП → усилитель → динамик; микрофон → предусилитель → АЦП |
| Фазовращатель / линия задержки | Цифровая дробная задержка (КИХ-фильтр или БПФ) |
| Цифровое диаграммообразование (ДОС) | Python/C-код: задержка-сумма, MVDR |
| Опорный генератор, синхронизация | Общий тактовый генератор звуковой карты |
| Калибровка каналов | Измерение АЧХ/ФЧХ каждого канала опорным микрофоном |
| Зондирующий сигнал (ЛЧМ) | Звуковой «чирп» 2 → 4 кГц |
| Эхо от цели, дальность | Отражение от стены / человека / щита |
| Доплер | Движение руки: 1 м/с на 3 кГц даёт сдвиг ≈ 17.5 Гц |

## 2. Базовая конфигурация и расчёт

Предлагаемая стартовая решётка: **8 элементов, шаг d = 4 см, апертура 32 см**
(вариант развития — 16 элементов, 64 см). Шаг 4 см выбран из двух соображений: он
допускает сканирование во всём секторе ±90° без дифракционных лепестков до
c/(2d) ≈ 4.3 кГц, и в него ещё помещаются доступные малогабаритные динамики.

Условие отсутствия дифракционных лепестков: `f < c / (d · (1 + |sin θ_max|))`.
Для d = 4 см: 8.6 кГц (только нормаль), 5.7 кГц (±30°), 4.6 кГц (±60°).

Расчёт — `python scripts/design_calc.py`:

**N = 8, d = 4 см**

| f, Гц | λ, см | ширина луча −3 дБ (нормаль) | при 30° | граница дальней зоны 2D²/λ, м |
|---|---|---|---|---|
| 500 | 68.6 | 146° | 117° | 0.30 |
| 1000 | 34.3 | 57° | 77° | 0.60 |
| 2000 | 17.2 | 28° | 33° | 1.19 |
| 3000 | 11.4 | 18° | 21° | 1.79 |
| 4000 | 8.6 | 14° | 16° | 2.39 |

**N = 16, d = 4 см**

| f, Гц | ширина луча (нормаль) | при 30° | 2D²/λ, м |
|---|---|---|---|
| 1000 | 28° | 32° | 2.4 |
| 2000 | 14° | 16° | 4.8 |
| 4000 | 7° | 8° | 9.6 |

Вывод: **рабочий диапазон демонстраций — примерно 1.5–4.3 кГц**. Ниже ~1 кГц
решётка из 8 элементов практически ненаправленная (λ больше апертуры) — это не
недостаток, а тоже отличная иллюстрация: «почему у РЛС метрового диапазона
огромные антенны».

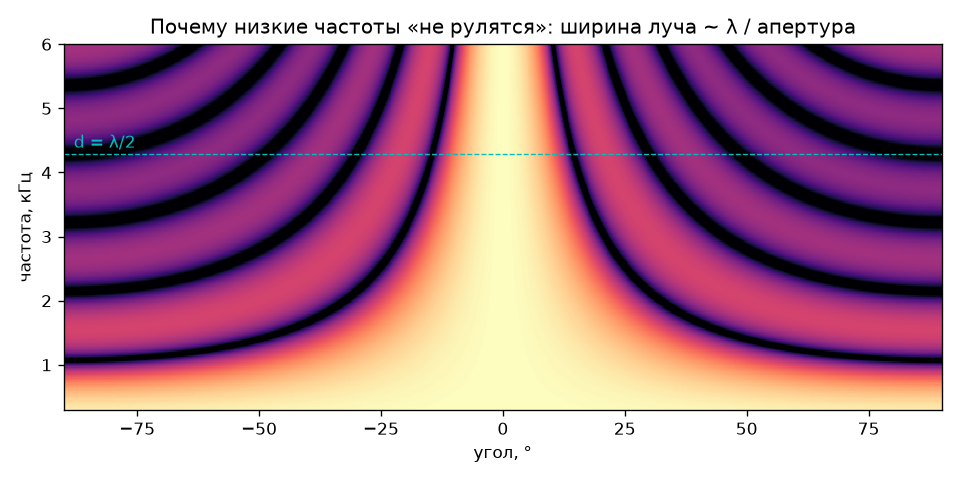
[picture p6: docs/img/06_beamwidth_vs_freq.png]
Ширина луча в зависимости от частоты


### Квантование задержки

Если задержки делать сдвигом на целое число отсчётов, это аналог дискретного
фазовращателя:

| fs, кГц | шаг задержки, мкс | путь звука за шаг, мм | макс. фазовая ошибка на 4 кГц | ≈ разрядность фазовращателя |
|---|---|---|---|---|
| 16 | 62.5 | 21.4 | ±45° | 2 бита |
| 48 | 20.8 | 7.1 | ±15° | 3.6 бита |
| 96 | 10.4 | 3.6 | ±8° | 4.6 бита |

Поэтому используем **дробные задержки** (КИХ-фильтр sinc или БПФ) — точность
ограничена только калибровкой. Сравнение — на рисунке ниже.

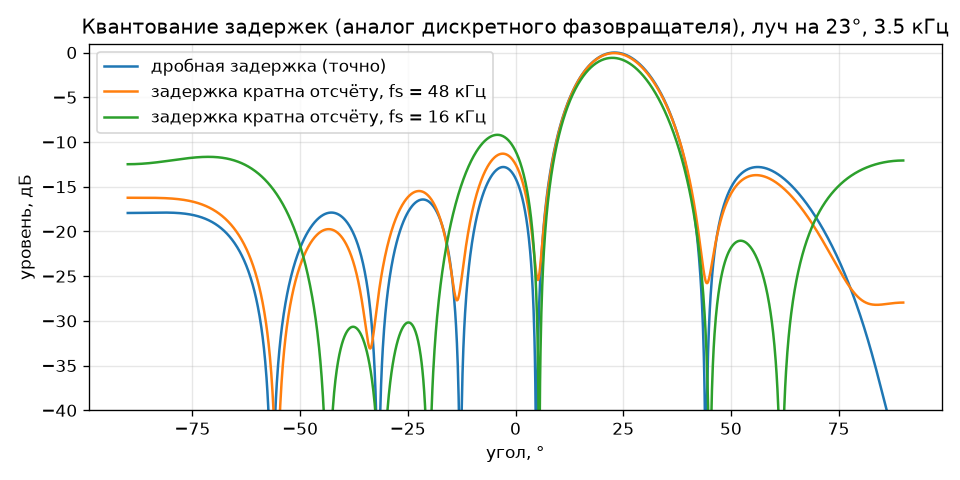
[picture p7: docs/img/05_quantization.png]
Квантование задержек


## 3. Демонстрационные сценарии

Каждый сценарий показывает один принцип ЦАФАР. Все они уже смоделированы в
`scripts/` — для передающих есть 8-канальные WAV для реальной решётки и
«виртуальные слушатели» (моно-WAV, что слышит человек под данным углом).

| # | Сценарий | Что слышит/видит зритель | Принцип ЦАФАР |
|---|---|---|---|
| 1 | **Бегущий луч** (`sweep_8ch.wav`) | Звук «прокатывается» по залу слева направо и обратно, хотя ничего не движется | Электронное сканирование без механики |
| 2 | **Два луча — два сигнала** (`two_beams_8ch.wav`) | Левая половина зала слышит мелодию, правая — «чирпы» | Многолучевость: несколько независимых лучей одновременно — только в цифровой решётке |
| 3 | **Звуковая призма** (`prism_phase_8ch.wav` vs `prism_ttd_8ch.wav`) | С фазовращателями высота шума меняется при ходьбе по залу; с истинными задержками — нет | Beam squint: фазовращатель ≠ линия задержки для широкополосного сигнала |
| 4 | **Дифракционные лепестки** | Повышаем частоту (или выключаем каждый второй динамик) — появляется второй «призрачный» луч | Условие d ≤ λ/2 |
| 5 | **Амплитудное распределение** | Сбоку от луча становится тише, сам луч чуть шире | Боковые лепестки и окна Тейлора/Чебышёва |
| 6 | **Акустический прожектор** (`focus_8ch.wav`) | Звук собирается в точку, где стоит зритель | Фокусировка в ближней зоне |
| 7 | **Акустическая камера** (приём) | На экране «горят» пятна там, где кто-то говорит | Пространственный спектр, многолучевой приём |
| 8 | **Направленное ухо** (приём) | В наушниках слышно только того, куда «навели» луч мышкой | Приёмное ДОС, выигрыш решётки |
| 9 | **Подавление помехи** (приём) | Громкий «шумовой» динамик исчезает, голос остаётся | Адаптивное ДОС (MVDR/Кейпон), нуль ДН на помеху |
| 10 | **Акустический радар** | ЛЧМ-«чирпы», на экране — отметки от людей/щитов по дальности и азимуту, доплер от движения руки | Полный цикл РЛС: излучение, приём, сжатие, ДОС |
| 11 | **Отказ элементов, калибровка** | Выключаем/«расстраиваем» каналы — луч разваливается; после калибровки собирается | Роль калибровки и деградация ФАР |

### Что уже показывает моделирование

* Сканирование (сценарий 1): луч следует заданному направлению, контраст ~20 дБ.
  Сканирование
* Два луча (сценарий 2): слушатель на −35° слышит мелодию на ~26 дБ громче чирпов,
  слушатель на +35° — чирпы на ~15 дБ громче мелодии.
* Призма (сценарий 3): при фазовом управлении «центр тяжести» спектра у слушателя
  смещается с 3.2 кГц (20°) до 1.6 кГц (70°) — на слух это отчётливое изменение тембра.
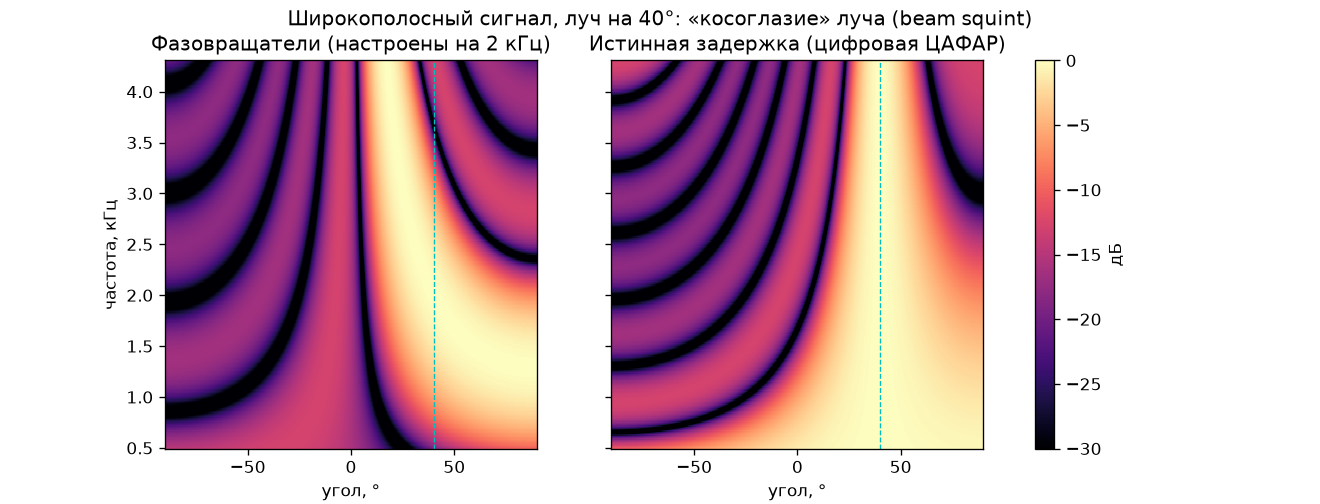
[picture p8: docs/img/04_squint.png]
Косоглазие луча
  
* Приём (сценарии 7–9), 2 источника на 5 м, 8 микрофонов:

  | выход | отношение цель/помеха |
  |---|---|
  | один микрофон | +3.7 дБ |
  | луч «задержка-сумма» на цель | +21 дБ |
  | адаптивный луч MVDR на цель | +64 дБ (идеальное свободное поле!) |

  В реальной комнате с отражениями и неидеальной калибровкой ожидаемо на порядок
  скромнее (ориентир — 10–25 дБ), но эффект всё равно отчётливо слышен.
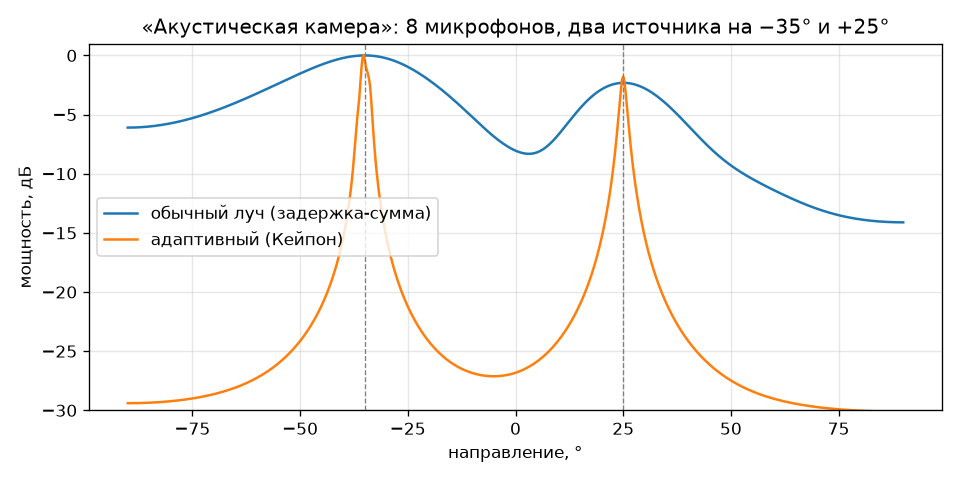
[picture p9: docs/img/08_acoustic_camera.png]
Акустическая камера
  

Поучительная деталь, найденная при моделировании: если обучать MVDR на смеси, где
присутствует сам полезный сигнал, при малейшем рассогласовании модели он начинает
**подавлять цель** («самоподавление»). Поэтому ковариация оценивается по участку, где
есть только помеха, — ровно так же, как обучающая выборка в РЛС.

## 4. Аппаратные варианты

Ключевое требование к «цифровой части»: **все каналы от одного тактового генератора**.
Несколько независимых USB-звуковых карт использовать нельзя — их часы расходятся,
и луч «поплывёт».

### Уровень 1 — «Слышно всем» (только передача, минимальный бюджет)
* ПК/ноутбук + USB-звуковая карта 7.1 (8 аналоговых выходов с одного кодека).
  Проверить: все 8 каналов независимы, ОС не делает upmix/bass management,
  канал LFE не фильтруется.
* 8 малогабаритных широкополосных динамиков Ø 30–40 мм на общей панели с шагом 4 см.
* 4 стереоусилителя класса D малой мощности (или один многоканальный).
* ПО — уже есть: `make_tx_demo.py` генерирует 8-канальные WAV.

### Уровень 2 — «Акустическая камера» (приём)
* Готовый USB-массив микрофонов (например, miniDSP UMA-16: 16 MEMS 4×4, шаг ≈ 4 см —
  уточнить характеристики) — сразу даёт 2D-камеру.
* Или своими руками: цифровые MEMS-микрофоны с I²S/TDM-выходом (INMP441, ICS-43434,
  ICS-52000 с TDM). Такой микрофон — уже **цифровой элемент со встроенным АЦП**,
  прямой аналог элемента ЦАФАР. Чтение 8–16 микрофонов с общим тактированием —
  RP2040 (PIO), ESP32-S3, STM32 или ПЛИС.
* Экран с тепловой картой поверх видео с веб-камеры — самый зрелищный вариант.

### Уровень 3 — «Полная ЦАФАР» (приём + передача в каждом элементе)
* Аудиоинтерфейс класса 8 вход / 8 выход (студийные интерфейсы с 8 микрофонными
  предусилителями) — каждый канал = ППМ: динамик + микрофон.
* Встраиваемый вариант: кодек CS42448 (6 АЦП / 8 ЦАП, TDM) с Teensy 4.x или
  Raspberry Pi — автономный экспонат без ПК.
* Открывает сценарии 10–11: акустический радар, калибровка по внутреннему тракту.

## 5. Подводные камни (и как с ними жить)

1. **Реверберация.** В комнате отражения создают «ложные» источники. Решения:
   большой зал, звукопоглощающие панели за и вокруг решётки, короткие импульсные
   сигналы, демонстрация на улице. Для радарного режима — стробирование по дальности.
2. **Низкие частоты не управляются.** Контент для демонстраций — 1.5–4.3 кГц
   (мелодии в 6–7 октаве, полосовой шум, чирпы). Для речи нужна решётка побольше
   или вложенные решётки (разные шаги для разных полос — как в многодиапазонных ФАР).
3. **Разброс элементов.** Динамики одной партии отличаются по чувствительности и фазе
   на единицы дБ и десятки градусов → обязательна калибровка опорным микрофоном
   (измерить импульсную характеристику каждого канала, выровнять КИХ-фильтром).
4. **Собственная направленность и взаимное влияние динамиков** — аналог ДН элемента
   и взаимной связи в ФАР. Нужна общая жёсткая панель (экран).
5. **Задержка ОС в реальном времени.** Первые демо — готовые WAV; интерактив — через
   ASIO/JACK/CoreAudio с малым буфером или на микроконтроллере.
6. **Громкость и безопасность.** Высокие частоты 3–4 кГц — область максимальной
   чувствительности слуха: держать уровень умеренным (< 80 дБА у зрителей).
7. **Температура.** Скорость звука меняется на ~0.6 м/с на °C — для точной
   фокусировки учитывать (аналог учёта условий распространения).

## 6. Дорожная карта

| Этап | Результат | Статус |
|---|---|---|
| 0. Моделирование | Библиотека `dpaa`, графики, WAV для решётки и «виртуальных слушателей», тесты | ✅ начато (этот репозиторий) |
| 1. Решётка 16 эл. на ПЛИС (приём + передача) | Живые сценарии 1–9; железо и прошивка — [docs/hardware](hardware/architecture.md) | 🔧 схемы и RTL готовы, закупка |
| 2. Приём: камера и адаптивка | Акустическая камера, «направленное ухо», MVDR (7–9) | ⏳ «направленное ухо» уже в RTL |
| 3. Калибровка | Автоматическое измерение и выравнивание каналов (11) | ⏳ |
| 4. Акустический радар | ЛЧМ, сжатие импульса, дальность-азимут, доплер (10) | ⏳ |
| 5. Интерактивный экспонат | Реальное время, управление с планшета/джойстика, визуализация | ⏳ |

Параметры радарного режима (оценка для полосы чирпа 2–4 кГц): разрешение по
дальности c/(2B) ≈ 8.6 см; при периоде повторения 100 мс однозначная дальность
≈ 17 м; доплер от движения руки 1 м/с на 3 кГц ≈ 17.5 Гц — различим при
длительности пачки ≥ 0.1 с.

## 7. Решения по формату (приняты)

* Аудитория: школьная конференция и музей кафедры → автономный экспонат с пультом на планшете.
* Приём и передача, акцент на передаче → 16 «ППМ» (динамик + микрофон).
* Бюджет ≤ 1000 $, только МК/ПЛИС → ULX3S (ECP5 + ESP32), ≈ 820 $ с резервом.

## 8. Открытые вопросы

* Помещение музея: размеры, отделка стен (реверберация), где встанет экспонат.
* Нужен ли большой экран (HDMI от ПЛИС) для «акустической камеры», или хватит планшета.

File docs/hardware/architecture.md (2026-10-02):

# Аппаратная архитектура: 16-элементная акустическая ЦАФАР на ПЛИС

## Исходные требования

| Требование | Решение |
|---|---|
| Школьная конференция, музей кафедры | Автономный экспонат: включил в розетку — работает; управление с планшета по Wi‑Fi |
| И приём, и передача (в основном передача) | Каждый элемент = динамик + микрофон («ППМ»), 16 элементов |
| Бюджет ≤ 1000 $ | ≈ 630 $, с резервом 15 % ≈ 725 $ (см. [bom.md](bom.md)) |
| 100 % МК/ПЛИС, ноутбук только для управления и отладки | ПЛИС ECP5 на модуле Colorlight i9 + ESP32-S3 (Wi‑Fi-пульт); ноутбук по USB |

## Главные решения

1. **16 элементов, шаг 40 мм, апертура 64 см.** Ширина луча ≈ 7° на 4 кГц и ≈ 14° на
   2 кГц; сканирование ±90° без дифракционных лепестков до 4.3 кГц. Нужно 19 выходов
   и 17 входов ПЛИС; у Colorlight i9 свободных выводов больше 100, так что есть запас
   на плоскую решётку 8 × 4.
2. **Цифровой элемент.** Усилитель MAX98357A принимает I2S и сам содержит ЦАП и
   усилитель класса D; MEMS-микрофон ICS-43434 содержит АЦП и выдаёт I2S. Динамик и микрофон стоят
   в общем 3D-печатном корпусе-«плитке» 40 × 60 мм ([mechanics.md](mechanics.md)).
   Оба — **готовые модули** на проводах Dupont; своя плата в установке одна —
   распределительная, и её собирает фабрика ([purchase.md](purchase.md)).
   Граница «аналог/цифра» проходит **внутри элемента** — ровно как в настоящей ЦАФАР.
   Между распределительной платой и элементами идут только цифровые сигналы
   3.3 В, аналоговых проводов нет, помехи на шлейфах не страшны.
3. **Когерентность «по построению».** Все 32 преобразователя тактируются одними
   BCLK = 3.125 МГц и LRCLK = 48 828 Гц от ПЛИС. Задержки между каналами создаются
   только цифровой обработкой.
4. **Вся обработка сигналов — в ПЛИС** (детерминированно, отсчёт в отсчёт):
   генераторы сигналов, формирование лучей на передачу и приём, измерители уровня.
   ESP32-S3 (отдельная плата DevKit, соединена с ПЛИС по UART) — «пульт»: Wi‑Fi-точка
   доступа, веб-страница для планшета, расчёт таблиц задержек (тригонометрия) и
   запись их в ПЛИС; прошивка — [firmware/esp32](../../firmware/esp32/README.md).
5. **Открытые инструменты.** Yosys + nextpnr + ecppack — бесплатно, без лицензий,
   работает на любом ноутбуке. Проект уже синтезирован и разведён (см. ниже).

## Структурная схема

Структурная схема установки

Исходник — `scripts/draw_block_diagram.py` (PNG для слайдов: `docs/img/structure.png`).
Соединения плат, разъёмы и кабели — [схема соединений](wiring.md).

### Полная структурная схема

Всё без объединений и сокращений: каждый из 16 элементов со своими модулями и
проводами, все 13 буферов распределительной платы с отводами на контакты разъёмов,
все блоки прошивки ПЛИС с регистровой шиной, цепи питания с предохранителями и
стабилизаторами, кабели W1–W28 и разъёмы; внизу — расшифровка всех сокращений и
позиционных обозначений. Для печати на плакат (A1/A0) — `docs/img/full_diagram.png`
(3600 пикселей по ширине) или векторный SVG.

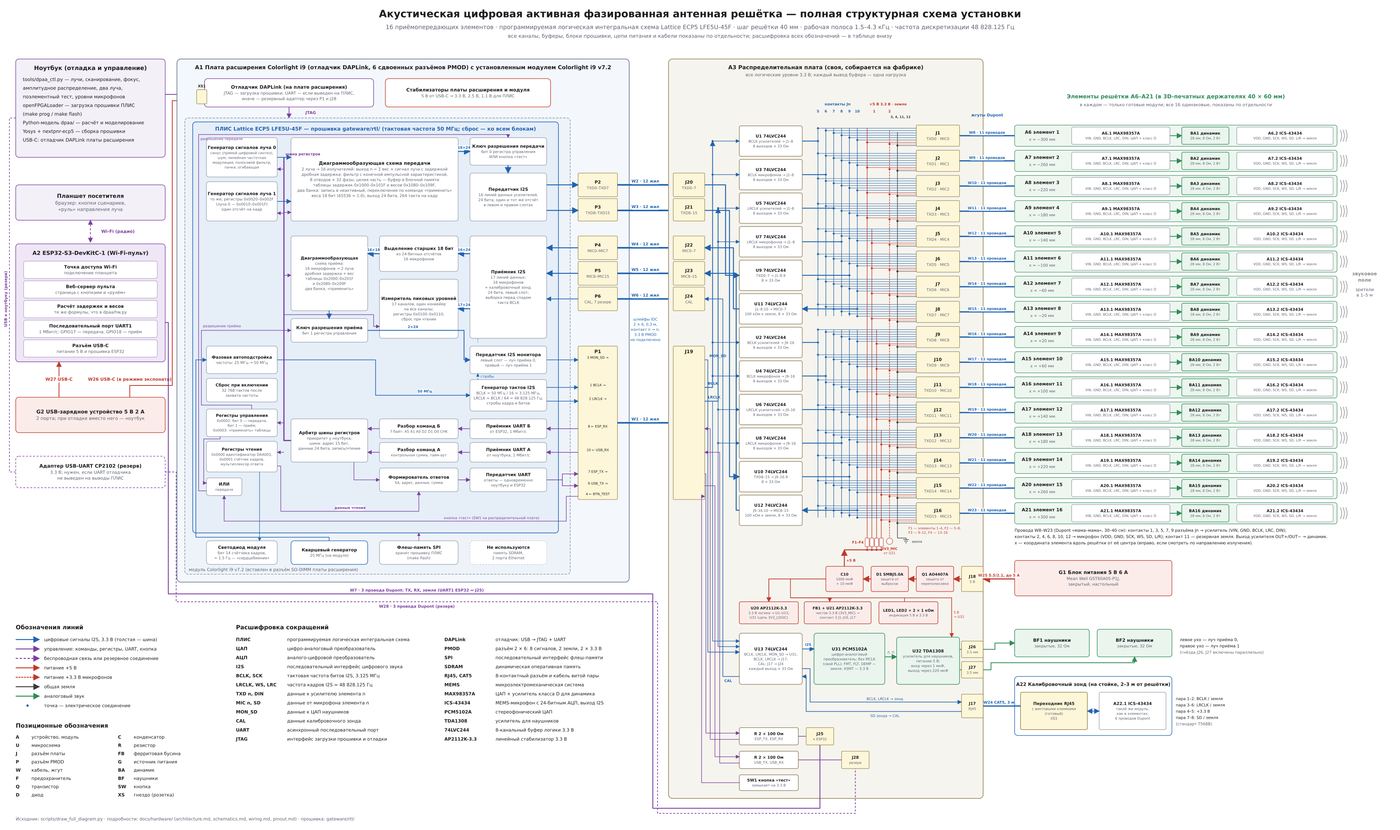
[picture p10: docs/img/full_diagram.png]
Полная структурная схема установки


Исходник — `scripts/draw_full_diagram.py`.
Ниже та же схема упрощённо, в виде Mermaid-диаграммы.

```mermaid
flowchart LR
    ESP["ESP32-S3 DevKit<br/>Wi‑Fi, веб-пульт,<br/>расчёт задержек"]
    subgraph I9["Colorlight i9 + плата расширения"]
        direction TB
        subgraph FPGA["ПЛИС ECP5 LFE5U-45F"]
            direction TB
            UART["UART-команды<br/>регистры"]
            GEN["2 генератора<br/>синус / шум / ЛЧМ / пачки"]
            DOSTX["ДОС передачи<br/>2 луча → 16 каналов<br/>дробная задержка + вес"]
            DOSRX["ДОС приёма<br/>16 каналов → 2 луча"]
            I2S["I2S: общий BCLK/LRCLK<br/>16 выходов, 17 входов"]
            GEN --> DOSTX --> I2S
            I2S --> DOSRX
            UART --> GEN & DOSTX & DOSRX
        end
    end
    ESP -- "UART 1 Мбод" --> UART
    NB["Ноутбук<br/>dpaa_ctl.py, отладка"] -- "USB (DAPLink: JTAG + UART)" --> UART
    TAB["Планшет посетителя"] -. Wi‑Fi .-> ESP
    I2S == "шлейфы PMOD" ==> HUB["Распределительная плата<br/>буферы 74LVC244, питание 5 В"]
    HUB ==> E1["Элемент 1<br/>модуль MAX98357A + динамик<br/>модуль ICS-43434"]
    HUB ==> E2["…"]
    HUB ==> E16["Элемент 16"]
    HUB --> DAC["PCM5102A + TDA1308 (на плате)<br/>→ наушники (2 луча приёма)"]
    HUB --> CAL["Калибровочный<br/>микрофон-зонд"]
    PSU["БП 5 В 6 А"] --> HUB
```

## Тракт сигнала и численные параметры

| Параметр | Значение |
|---|---|
| Системная частота ПЛИС | 50 МГц (PLL из 25 МГц) |
| Частота дискретизации | 50 МГц / 1024 = **48 828.125 Гц** |
| BCLK / кадр I2S | 3.125 МГц, 64 такта (2 × 32 бита), данные 24 бита |
| Разрешение задержки | 1/32 отсчёта = 0.64 мкс = 0.22 мм пути звука (≈ 0.7° фазы на 3 кГц) |
| Фильтр дробной задержки | 8 отводов, 32 фазы, ошибка ≤ −78 дБ до 5.9 кГц |
| Диапазон задержек | 3 … 248 отсчётов (до 5 мс, 1.7 м пути — хватает и для фокусировки) |
| Разрядность | отсчёты и коэффициенты 18 бит (умножители 18×18), выход 24 бита |
| Лучи на передачу | 2 независимых (у каждого свой генератор и своя таблица задержек/весов) |
| Лучи на приём | 2 (левое и правое ухо наушников) |
| Смена луча | атомарно, по команде commit, на границе кадра — без щелчков |
| Задержка обработки | 2–3 отсчёта (≈ 50 мкс) |
| Управление | UART 1 Мбод, 7-байтовые кадры с контрольной суммой, от ноутбука и от ESP32 |

Ресурсы ПЛИС (`gateware/check_all.sh`: синтез и разводка без привязки выводов,
router2), рабочая частота 50 МГц:

| Плата | Кристалл | LUT | Триггеры | Умножители 18×18 | Fmax |
|---|---|---|---|---|---|
| **Colorlight i9** | LFE5U-45F | 10 300 (23 %) | 5 700 (13 %) | 16 из 72 | 54 МГц |
| Colorlight i5 | LFE5U-25F | 10 300 (42 %) | 5 700 (23 %) | 16 из 28 | 56 МГц |
| ULX3S | LFE5U-85F | 10 400 (12 %) | 5 800 (6 %) | 16 из 156 | 55 МГц |

На i9 остаётся запас в 3–4 раза: туда войдут «акустическая камера», радарный режим
(ЛЧМ + сжатие) и расширение до 32 элементов. Запас по частоте небольшой (8–12 %),
поэтому после каждой правки RTL полезно запускать `check_all.sh`.

## Регистры управления

| Адрес | Доступ | Назначение |
|---|---|---|
| `0x0000` | R | идентификатор `0xDAA001` |
| `0x0001` | R | счётчик кадров |
| `0x0002` | R/W | bit0 — излучение разрешено, bit1 — приём разрешён (после включения: только приём) |
| `0x0003` | W | commit: bit0 — применить таблицы передачи, bit1 — приёма |
| `0x0010–0x001F` | W | генератор луча 0: режим, частота, амплитуда, ЛЧМ, пачки, огибающая, биквад |
| `0x0020–0x002F` | W | генератор луча 1 |
| `0x0100–0x0110` | R | пиковый уровень микрофона 1–16 и калибровочного (сброс при чтении) |
| `0x1000 + 2·o + b` | W | задержка элемента o для луча передачи b (формат Q11.5 отсчёта) |
| `0x1080 + 2·o + b` | W | вес элемента o для луча b (Q2.16, 65536 = 1.0, может быть отрицательным) |
| `0x2000 + 16·b + i` | W | задержка микрофона i для луча приёма b |
| `0x2080 + 16·b + i` | W | вес микрофона i для луча приёма b |

Кадр команды: `A5 A1 A0 D2 D1 D0 CHK`, `CHK = A1^A0^D2^D1^D0^0x5A`, старший бит A1 = 1 —
чтение; ответ `5A A1 A0 D2 D1 D0 CHK`. Эталон формирования кадров и таблиц — `dpaa/hw.py`.

## Амплитудное распределение

Вес каждого элемента — отдельный регистр 18 бит (Q2.16) для каждого луча, на передаче
и на приёме, поэтому распределение задаётся полностью программно и меняется «на лету»
вместе с лучом:

* окна: равномерное, Тейлор, Чебышёв, Ханн с заданным уровнем боковых лепестков
  (`dpaa_ctl.py --taper taylor --sll 35 …`);
* произвольные веса, в том числе отрицательные — например, разностная ДН для
  демонстрации моноимпульсного пеленгования (`--weights 1,…,1,-1,…,-1`);
* выключение элементов — «отказы» и прореживание решётки (`--off 2,4,6,…`).

Точность весов ПЛИС (≈ 10⁻⁵) на практике не ограничивает: реальный предел —
разброс динамиков. При случайных ошибках ±1 дБ по амплитуде и ±10° по фазе средний
уровень боковых лепестков 16-элементной решётки ≈ −25 дБ, поэтому окна глубже −25…−30 дБ
имеют смысл только после калибровки по зонду.

## Питание и громкость

* MAX98357A при 5 В: до 3.2 Вт на 4 Ом, но экспонату столько не нужно. Типичный
  режим — до 0.25 Вт на канал, что при когерентном сложении 16 элементов (+24 дБ по
  оси луча) даёт порядка 90 дБ на 1 м даже с малыми динамиками — **громкость надо
  ограничивать**, а не добывать. Усиление MAX98357A выставлено на 6 дБ, в
  программах пульта громкость ограничена половиной шкалы.
* Бюджет тока: 16 × ≤ 0.3 А (средний в пиках) ≈ 5 А в худшем случае →
  БП 5 В 6 А (закрытый настольный, безопасно для школы), ПЛИС питается отдельно по USB.
* Уровень у зрителей держать < 80 дБА: частоты 2–4 кГц — зона максимальной
  чувствительности слуха.

## Механика

* Передняя панель ~700 × 250 мм (фанера 6–8 мм или акрил), 16 отверстий под динамики
  Ø 28–30 мм с шагом 40 мм, над каждым — отверстие Ø 3 мм для микрофона (на той же
  координате x, на 30–35 мм выше центра динамика).
* Модули элементов стоят за панелью перпендикулярно ей; сзади — звукопоглощающий
  поролон (подавляет излучение назад и отражения внутри корпуса).
* Спереди — акустически прозрачная ткань; стойка на высоте 1.2–1.4 м (уровень ушей
  школьника), разметка углов на полу (−60°…+60°) — «шкала», по которой ходят зрители.

## Выбор платы ПЛИС

Требования: около 40 свободных выводов (19 выходов + 17 входов + UART), до 52 выводов
для плоской решётки 8 × 4; ресурсы для двух ядер формирования лучей; дёшево и
доступно на AliExpress; желательно — открытые инструменты.

| Плата | ПЛИС | Выводы | ≈ Цена | Итог |
|---|---|---|---|---|
| **Colorlight i9 + плата расширения** | ECP5 LFE5U-45F (44K LUT) | 100+ (6 сдвоенных PMOD), USB DAPLink | 45–70 $ | **выбрана**: та же семья, что у ULX3S, проект переносится без изменений ядра |
| Colorlight i5 + плата расширения | ECP5 LFE5U-25F (24K LUT) | те же | 35–55 $ | запасной вариант: проект занимает 42 % LUT и 16 из 28 умножителей — камера и радар поместятся с трудом |
| QMTech Artix-7 XC7A35T (core board) | Xilinx Artix-7 (20.8K LUT6 ≈ 33K лог. ячеек) | ~100 на двух разъёмах 2 × 32 | 40–90 $ | подходит по ресурсам; нужен Vivado, замена PLL и файла ограничений |
| Sipeed Tang Primer 20K / 25K | Gowin GW2A-18 / GW5A-25 (~20–23K LUT) | ~40–50 | 30–40 $ | мало: оценка синтеза — около 36K LUT (без переноса умножителей в DSP) |
| ULX3S | ECP5 LFE5U-85F | 56 + ESP32 на плате | 165 $ у Crowd Supply/Mouser, у перепродавцов — до 500 $ | поддерживается (`make BOARD=ulx3s`), но дорого |
| Только МК (STM32H7, Teensy 4.1, RP2350) | — | — | 10–30 $ | мало независимых линий I2S (нужно 16 + 17), трудно гарантировать синхронность |

У Colorlight нет встроенного Wi‑Fi, поэтому пульт — отдельная ESP32-S3 DevKit (≈ 10 $),
соединённая с ПЛИС по UART. Это даже удобнее: ESP32 прошивается независимо от ПЛИС.

## Масштабирование

* 16 → 32 элемента (8 × 4): у Colorlight i9 хватает выводов (32 выхода + 16 входов
  при двух микрофонах на линию). Для 64 элементов — TDM-усилители или вторая плата ПЛИС
  с общим тактом.
* 2D-решётка (4 × 4 или 8 × 8) для сканирования по углу места — то же ядро, другая
  таблица задержек (геометрия задаётся только программой).

## Порядок запуска железа (bring-up)

1. Плата ПЛИС без периферии: загрузить битстрим, светодиод мигает (~1.5 Гц);
   `python tools/dpaa_ctl.py --port … id` → `ID = 0xdaa001`.
2. Распределительная плата без модулей: осциллографом BCLK 3.125 МГц, LRCLK 48.8 кГц
   на всех 16 разъёмах; питание 5 В и 3.3 В.
3. Один модуль: кнопка «тестовый тон» — тон 3 кГц (проверка без команд);
   `peaks` — уровень микрофона растёт, если хлопнуть рядом.
4. Все 16 модулей: `elements` — элементы звучат по очереди слева направо
   (проверка порядка подключения и полярности).
5. Калибровка: зонд на 2–3 м по нормали, измерение задержки и уровня каждого
   канала, запись поправок (этап 3 дорожной карты).
6. Сценарии: `beam`, `sweep`, `two-beams`, `focus`, `listen`.

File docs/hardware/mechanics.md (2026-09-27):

# Элемент решётки: динамик + микрофон в одном корпусе

## Выбор преобразователей

### Динамик: массовый круглый 28 мм, 8 Ом, 2 Вт

Точная модель не важна. В рабочей полосе 1.5–4.3 кГц любой исправный микродинамик
звучит ровно, а разницу между экземплярами убирает калибровка. Поэтому берём самый
распространённый и дешёвый вариант, одной партией и с запасом.

| Параметр держателя `speaker` | **`rd28`** (основной) | **`ov1524`** (равноценная замена) | `rd36` (самый дешёвый) | `rd32` | `sq32` |
|---|---|---|---|---|---|
| Что это | круглый 28 мм, 8 Ом, 2 Вт, внутренний магнит | овальный 15 × 24 мм, 8 Ом, 0.8 Вт (макс. 1 Вт), 500–10 000 Гц | круглый 36 мм майларовый, 8 Ом, 1 Вт | Dayton Audio CE32A-8 и аналоги | Visaton BF 32 S |
| Как искать | «28mm 8 ohm 2W speaker» (Gikfun AE1054, uxcell, HALJIA…) | «овальный динамик 8 Ом 1 Вт 15×24» | «36mm 8 ohm 1W mylar speaker» | — | — |
| Толщина | 5.5–10 мм | 3.5 мм | ≈ 5 мм | 14.5 мм | 11 мм |
| Цена | ≈ 0.5–3 $ | ≈ 0.5–2 $ | ≈ 0.3–1 $ | ≈ 5–20 $, часто нет в наличии | ≈ 15 $ |

Почему **8 Ом и не меньше 2 Вт**: MAX98357A от 5 В отдаёт в 8 Ом не больше ≈ 1.8 Вт.
Значит, даже при ошибке в программе (полная шкала) динамик не сгорит, а суммарный ток 16
усилителей укладывается в блок питания 5 В 6 А.

* Динамики **0.8–1 Вт** (`ov1524`, `rd36`) на полной шкале можно перегреть. `tools/dpaa_ctl.py` сам
  не даёт поднять уровень выше 0.5 шкалы (`MAX_AMP`), это не больше четверти мощности.
  Даже два луча сразу дают на элементе не больше половины шкалы (≈ 0.45 Вт).
  Опасна только ручная запись регистров в обход утилиты.
* Динамик **4 Ом 3 Вт** тоже безопасен для себя, но ток вдвое больше. На полной шкале
  всех 16 каналов блоку 6 А не хватит, поэтому такой вариант лучше не брать.

**Размеры в таблице — типовые.** Перед печатью измерьте свой динамик и, если нужно,
поправьте в `dpaa_element.scad` строку `spk_table`: диаметр рамы, монтажную глубину,
толщину обода и диаметр магнита. Раскрыв, гнездо, объём и упоры крышки пересчитаются сами.
Проверено, что влезает от 15 × 24 до 36 мм по диаметру и до 16 мм по глубине.

**Овальный `ov1524`** ставится длинной стороной вертикально: по ширине решётки он
занимает всего 15 мм. Форма на диаграмму не влияет — на 2–4 кГц длина волны 8–17 см,
намного больше динамика, и он излучает почти одинаково во все стороны. На нижнем краю
полосы (≈ 1.5 кГц) он тише 28-миллиметрового, для демонстрации это не критично.
Выводы у него всего 50 мм, поэтому объём за ним сделан мельче (10 мм вместо 16) — провода
дотягиваются через крышку и панель до колодки усилителя впритык. Если не хватит, нарастите
их двумя кусками провода с термоусадкой. Крышку прижимают четыре упора ближе к концам
овала: в середине у динамика магнит, внизу выходят провода.

| Овальный: разнесённый вид сзади | Овальный: вид спереди |
|---|---|
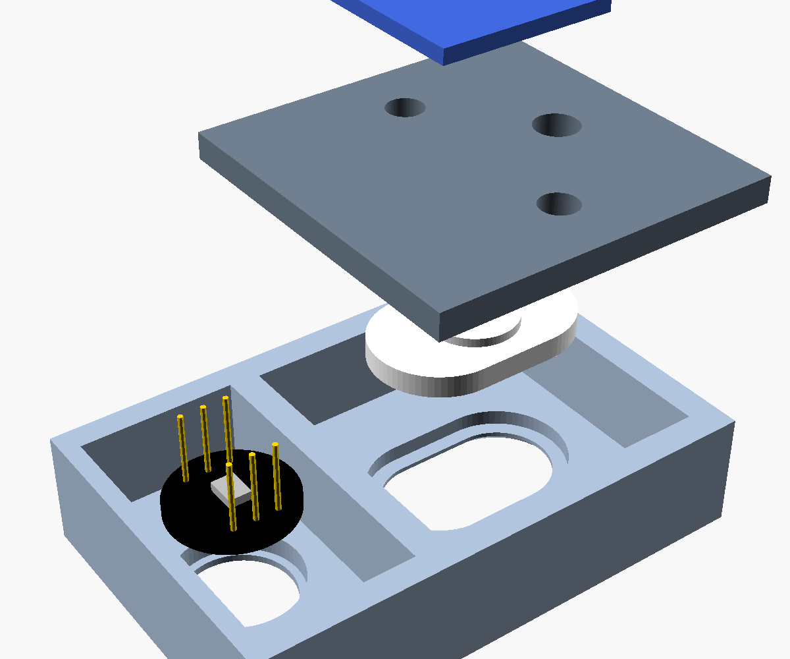
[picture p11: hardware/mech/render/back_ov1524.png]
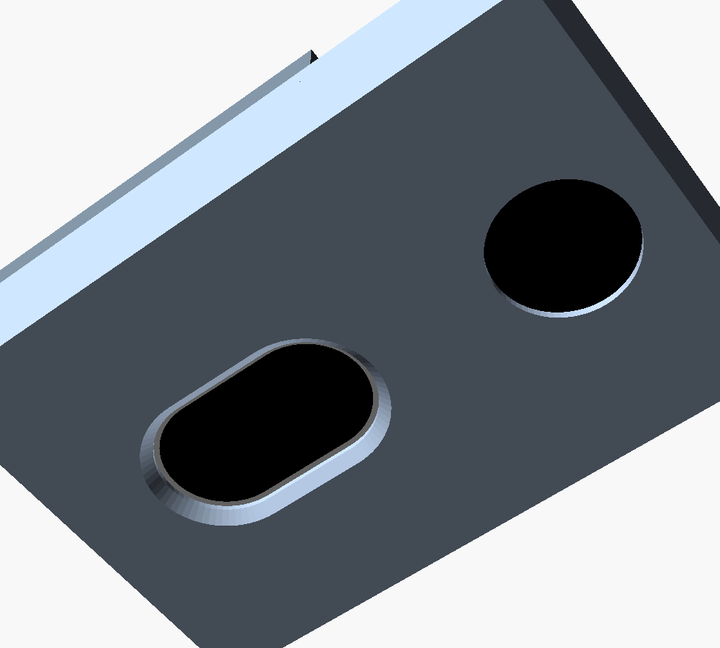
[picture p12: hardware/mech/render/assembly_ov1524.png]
|  |  |

### Микрофон: TDK InvenSense ICS-43434

* цифровой I²S-выход 24 бита — внутри уже есть АЦП, децимация и антиалиасинг;
* чувствительность −26 дБПШ при 94 дБ SPL, отношение сигнал/шум 65 дБА,
  максимальный уровень 120 дБ SPL (не перегружается даже в 2 см от работающего динамика);
* корпус 3.5 × 2.65 × 0.98 мм, звуковое отверстие снизу (через печатную плату);
* выпускается сейчас и заменяет снятый с производства INMP441 (тот же протокол);
* продаётся **готовым круглым модулем** с гребёнкой из 6 выводов (VDD, GND, SCK, WS, SD,
  L/R) — своя плата для микрофона не нужна.

### Можно ли взять готовый «динамик + микрофон в одном корпусе»?

Готовых компонентов с доступом к обоим сигналам и нужными параметрами практически нет:
такие сборки делают под конкретные телефоны и гарнитуры. Поэтому **общий корпус делаем
сами** — это напечатанный на 3D-принтере держатель, который объединяет динамик и
микрофон в один элемент. По смыслу это и есть приёмопередающий модуль ЦАФАР.

Любопытный факт для экскурсии: динамик по принципу обратимости сам работает как
микрофон. Но у MAX98357A нет приёмного тракта, а отдельный MEMS-микрофон даёт намного
более чистый приём, поэтому в элементе стоят два преобразователя.

## Держатель («плитка» 40 × 60 мм) под готовые модули

Файл модели — [`hardware/mech/dpaa_element.scad`](../../hardware/mech/dpaa_element.scad)
(OpenSCAD, все размеры — параметры в начале файла). Готовые STL и контуры задней
панели — в `hardware/mech/stl/`, пересборка — `hardware/mech/build.sh`.

| Разнесённый вид | Сборка |
|---|---|
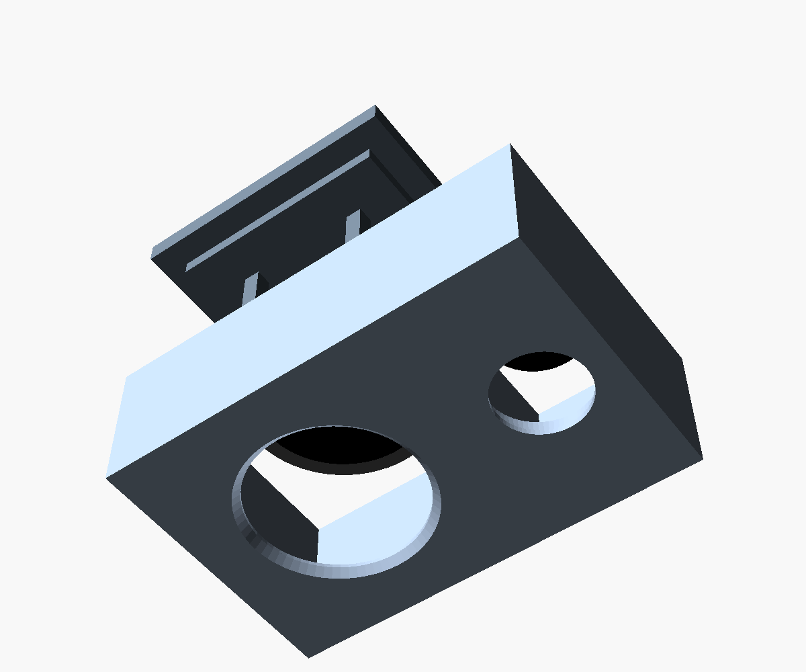
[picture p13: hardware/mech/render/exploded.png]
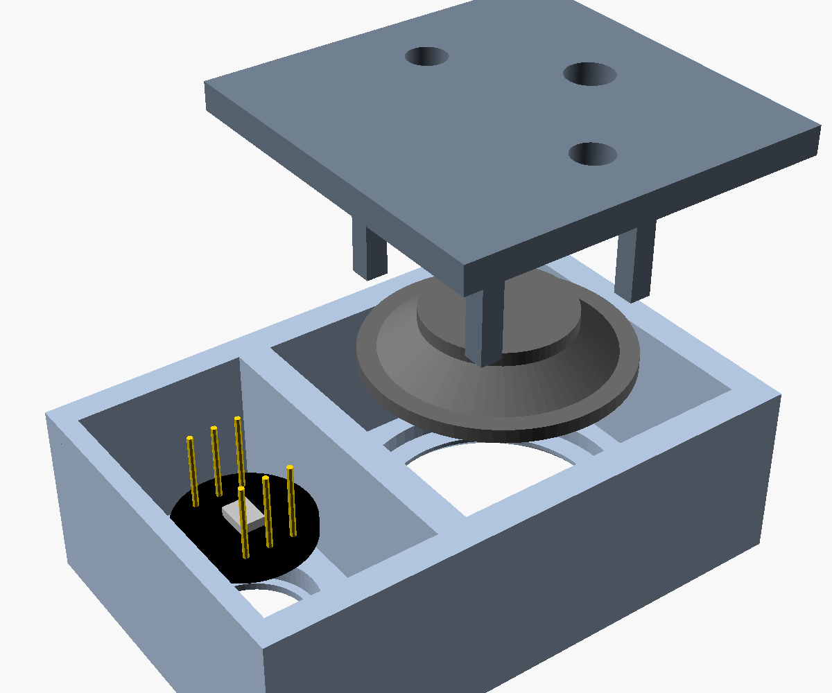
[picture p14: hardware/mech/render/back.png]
|  |  |

Устройство:

* **Плитка 39.6 × 59.6 мм** — шаг 40 мм по горизонтали (как у решётки), 60 мм по
  вертикали. Из одинаковых плиток собирается линейка 16 × 1; плоская решётка 8 × 4
  тоже возможна, но с вертикальным шагом 60 мм (дифракционные лепестки по углу места
  появятся раньше — примерно с 2.9 кГц при сканировании во всём секторе).
* **Внизу — динамик** в закрытом объёме ≈ 33 × 33 × 16 мм (для 36 мм — 37 × 37 × 16,
  для овального — 33 × 33 × 10): нет излучения
  назад, тыл динамика акустически отделён от микрофона. Раскрыв на 4.5 мм меньше рамы, с фаской.
* **Вверху — гнездо под готовый модуль ICS-43434**: сквозное отверстие Ø `mic_d`
  (по умолчанию 14.2 мм) с упорным бортиком спереди. Модуль вставляется сзади стороной
  со звуковым отверстием вперёд, выводы смотрят назад — к проводам Dupont. **Диаметр
  модуля продавцы не указывают: измерьте его и поправьте `mic_d`** (модуль + 0.2 мм).
* **Крышка** закрывает объём динамика: четыре упора прижимают обод рамы динамика, две
  латунные закладные M3 крепят плитку к задней панели, через отверстие выходят
  провода динамика (после монтажа — термоклей).
* **Модуль усилителя MAX98357A** крепится стяжкой к задней панели за динамиком — для
  него в панели есть прорези.

Микрофон стоит на 29.8 мм выше центра динамика. Для лучей в дальней зоне общий сдвиг
всех микрофонов ничего не меняет, а при фокусировке в ближней зоне он учитывается:
`dpaa/hw.py`, `MIC_OFFSET` и `mic_positions()`.

| Линейная решётка 16 × 1 | Плоская решётка 8 × 4 |
|---|---|
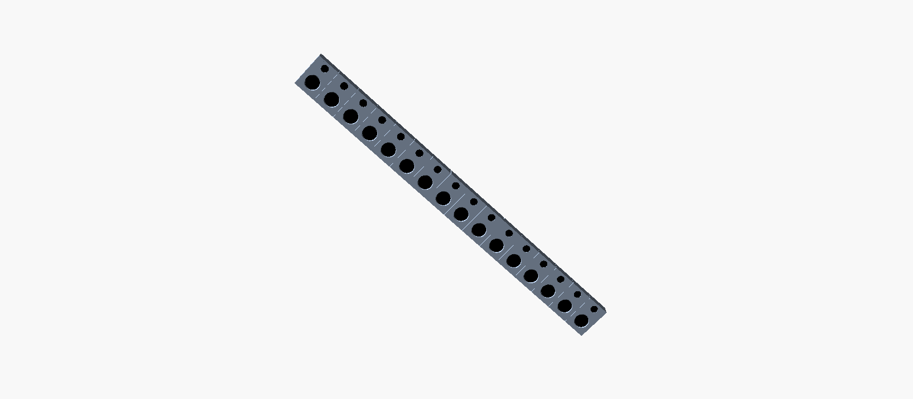
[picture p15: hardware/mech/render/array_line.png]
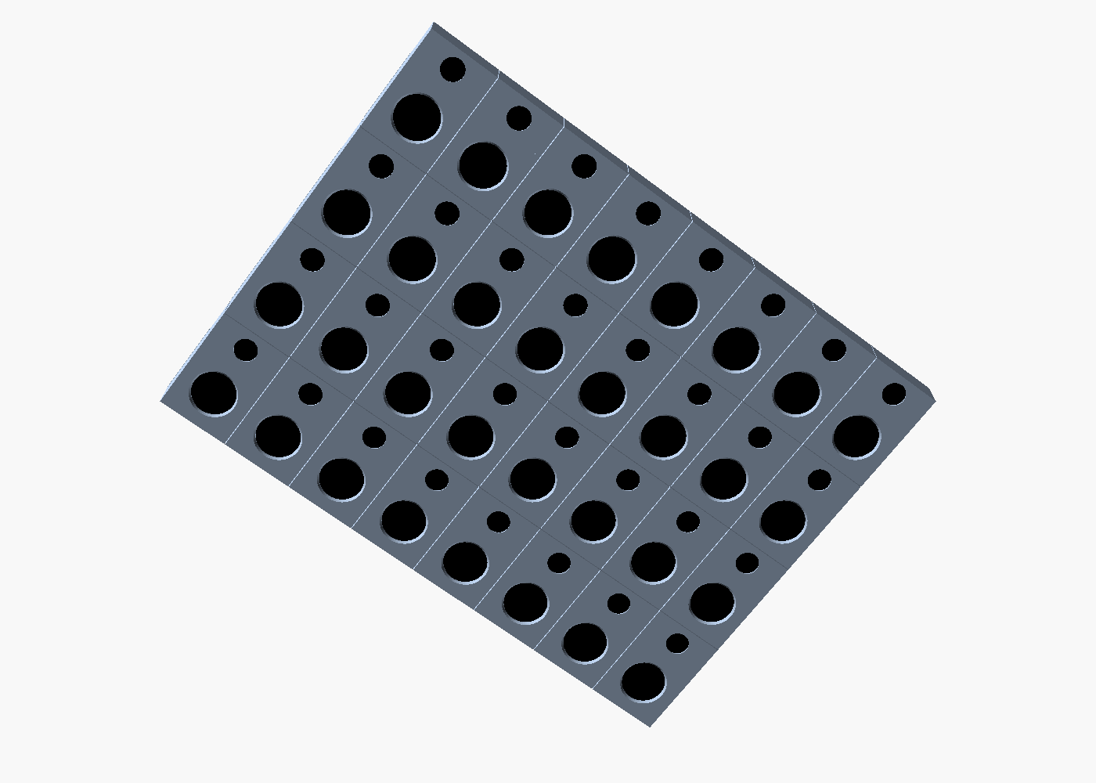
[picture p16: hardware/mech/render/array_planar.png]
|  |  |

### Печать

| Деталь | Файл | Ориентация | ≈ Пластик |
|---|---|---|---|
| Держатель | `holder_rd28.stl` (или `_ov1524`, `_rd36`, `_rd32`, `_sq32`) | лицом на стол | 12–15 г |
| Крышка | `back_rd28.stl` (или `_ov1524`, `_rd36`, `_rd32`, `_sq32`) | наружной стороной на стол | 5–6 г |

PETG или PLA, сопло 0.4 мм, слой 0.2 мм, 3–4 периметра, заполнение 30 %, без поддержек.
На 18 комплектов уходит ≈ 350 г пластика. Сначала напечатайте 1–2 пробных держателя и
проверьте посадку динамика и модуля микрофона. Для `rd36` стенки корпуса
тоньше (≈ 1.4 мм) — печатайте с 3 периметрами и без усадки (PETG).

### Сборка элемента (без пайки, если гребёнки модулей запаяны)

1. Вплавить паяльником две латунные закладные M3 × 4.5 в крышку.
2. Вставить модуль микрофона в верхнее гнездо сзади, звуковым отверстием вперёд;
   закрепить каплей термоклея по краю (отверстие не заливать).
3. Вложить динамик сзади, рамой к лицевой части (под раму — кольцо поролона 1 мм);
   вывести его провода через отверстие крышки, вставить крышку, залить отверстие термоклеем.
4. Прикрутить плитку к задней панели двумя винтами M3 × 8; модуль усилителя
   притянуть стяжкой к панели за динамиком, провода динамика — в колодку модуля.
5. Подключить провода Dupont: 5 — к усилителю, 6 — к микрофону (по надписям на модулях,
   раскладка — [pinout.md](pinout.md)).

### Задняя панель

Контуры для лазерной резки (фанера или акрил 4–5 мм): `panel_line.svg/.dxf` (16 × 1) и
`panel_planar.svg/.dxf` (8 × 4). Для каждого элемента: два отверстия M3, отверстие для
проводов динамика, окно к выводам микрофона и две прорези под стяжку модуля усилителя.
Именно панель задаёт точный шаг 40 мм, от которого зависит качество луча, поэтому её
лучше резать лазером.

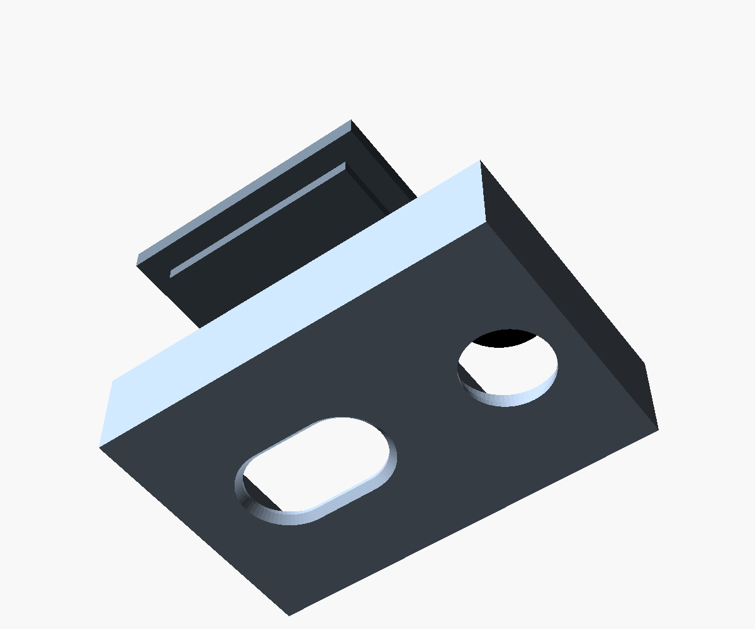
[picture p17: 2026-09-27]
hardware/mech/render/exploded_ov1524.png

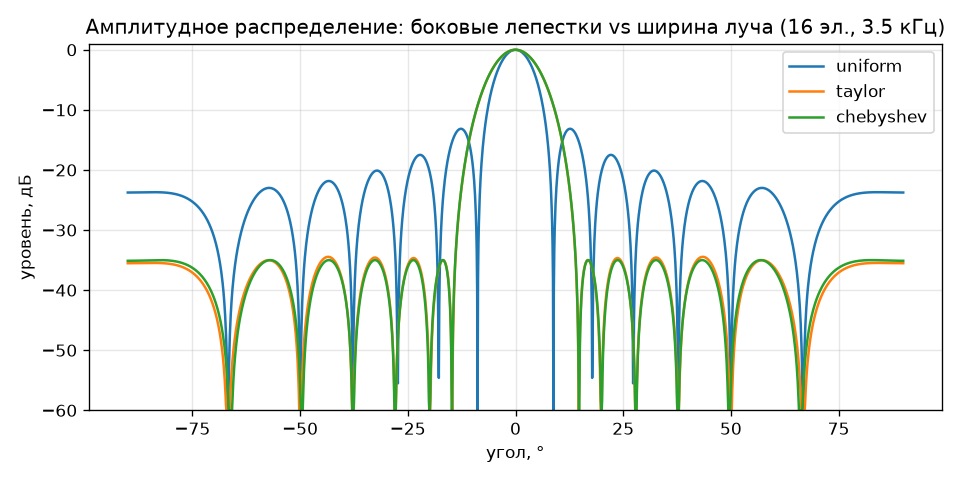
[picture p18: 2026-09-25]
docs/img/03_tapering.png

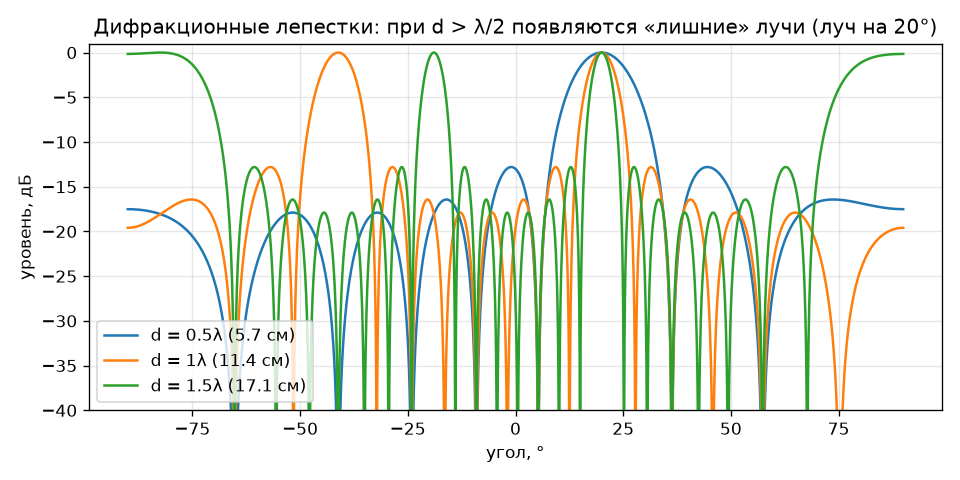
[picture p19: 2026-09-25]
docs/img/02_grating_lobes.png

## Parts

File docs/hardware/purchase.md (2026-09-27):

# Что купить и что заказать

Обозначения — как на [схеме соединений](wiring.md). Бюджет — [bom.md](bom.md).
**Принцип:** максимум готовых модулей, минимум ручного монтажа. Своя плата — одна,
и её собирает фабрика.

## 1. Готовые платы и модули (покупаются)

| Поз. | Название для поиска / заказа | Кол-во | Примечание |
|---|---|---|---|
| A1 | **Colorlight i9 v7.2** (ПЛИС LFE5U-45F) **+ extension board** (DAPLink, 6 PMOD) | 1 | в лоте должна быть плата расширения, не только модуль |
| A2 | **ESP32-S3-DevKitC-1** (например, N8R8) | 1 | подойдёт клон |
| A6.1 | **MAX98357A I2S Class D amplifier module** (Adafruit #3006 или клон) | 18 | 16 + 2; лучше вариант с запаянной гребёнкой |
| A6.2 | **ICS-43434 I2S MEMS microphone module** (круглый, 6 выводов: VDD, GND, SCK, WS, SD, L/R) | 20 | 16 + зонд + 3 запасных; **измерить диаметр** и вписать в `mic_d` модели держателя |
| — | **Переходник RJ45 с винтовыми клеммами** («RJ45 breakout / terminal board») | 1 | для калибровочного зонда |
| — | **USB-UART адаптер CP2102** (или CH340), 3.3 В | 1 | резерв |

## 2. Прочие покупные изделия

| Поз. | Название | Кол-во |
|---|---|---|
| BA1… | динамик **круглый 28 мм, 8 Ом, 2 Вт** (поиск: «28mm 8 ohm 2W speaker», например Gikfun AE1054) **или овальный 15 × 24 мм, 8 Ом, 1 Вт**, одной партии | 18 |
| G1 | блок питания **Mean Well GST60A05-P1J** (5 В 6 А, штекер 5.5/2.1) | 1 |
| G2 | USB-зарядник 5 В 2 А на 2 порта + 2 кабеля USB-C | 1 |
| BF1, BF2 | закрытые наушники 32 Ом, штекер 3.5 мм | 2 |
| W1–W6 | **готовые шлейфы IDC 2×6** (12 pin, 20–30 см) | 6 |
| W8–W23 | **провода Dupont «мама–мама»** 30 и 40 см, ленты по 40 шт. | 6 лент |
| W24 | патч-корд CAT5 3 м | 1 |

## 3. Своя плата — одна, заказывается собранной

| Поз. | Плата | Размер | Нужно / заказать | Монтаж |
|---|---|---|---|---|
| A3 | **Распределительная плата**: буферы 74LVC244 ×13, питание, ЦАП PCM5102A, драйвер наушников TDA1308, разъёмы | ~100 × 160 мм, 2 слоя | 1 / 2–5 | **на фабрике** (SMT + выводной монтаж, JLCPCB/PCBWay) |

**Файлов для фабрики пока нет:** схема проработана до уровня таблиц соединений
([schematics.md](schematics.md)). Следующий шаг — перенести плату в KiCad, развести и
выгрузить Gerber, BOM и файл координат для монтажа.

Больше своих плат нет: элементы собираются из готовых модулей (усилитель, микрофон,
динамик) на проводах Dupont, зонд — из готового модуля микрофона и переходника RJ45.

## 4. Изготовить по нашим файлам (не электроника)

| Что | Файлы | Как |
|---|---|---|
| Держатели элементов и крышки, 18 комплектов | `hardware/mech/stl/holder_rd28.stl`, `back_rd28.stl` (для овального — `_ov1524`) (под свой динамик — см. [mechanics.md](mechanics.md)) | 3D-печать, PETG |
| Задняя панель | `hardware/mech/stl/panel_line.svg` (или `.dxf`) | лазерная резка, фанера/акрил 4–5 мм |

## 5. Что остаётся сделать руками

* Запаять гребёнки модулей, если их прислали отдельно (11 выводов на элемент).
* Два провода динамика — к выходу модуля усилителя (у Adafruit — винтовая колодка).
* Вставить модули и динамик в держатель, прикрутить держатели к панели, подключить провода.

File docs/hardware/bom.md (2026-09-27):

# Спецификация и бюджет

Что именно покупать и что заказывать — [purchase.md](purchase.md).
Машиночитаемая версия — [`hardware/bom.csv`](../../hardware/bom.csv). Цены — ориентиры
в долларах США без доставки и пошлин; перед заказом проверьте актуальные цены и наличие.

**Принцип:** всё, что можно, — готовые модули; своя плата одна (распределительная),
и её собирает фабрика.

| Группа | Что | Кол-во | ≈ $ |
|---|---|---|---|
| Ядро | Colorlight i9 (LFE5U-45F) + плата расширения с DAPLink | 1 | 60 |
| | ESP32-S3-DevKitC-1 + запасной USB-UART | 1 | 13 |
| Элементы | Модуль усилителя MAX98357A | 18 | 108 |
| | Модуль микрофона ICS-43434 (круглый) | 20 | 100 |
| | Динамик круглый 28 мм, 8 Ом, 2 Вт (одной партии) | 18 | 27 |
| | Провода Dupont F–F 30–40 см | ~200 | 18 |
| | Держатели (3D-печать), закладные M3, стяжки | — | 25 |
| Распределительная плата | Плата A3, собранная на фабрике (с ЦАП и драйвером наушников) | 1 | 90 |
| | Наушники | 2 | 50 |
| Питание | БП 5 В 6 А, USB-зарядник на 2 порта | — | 30 |
| Кабели и зонд | шлейфы PMOD 2×6, переходник RJ45, CAT5 3 м | — | 15 |
| Механика | задняя панель, стойка, ткань, крепёж | 1 | 80 |
| Расходники | | | 15 |
| **Итого** | | | **≈ 630** |
| **С резервом 15 %** | на брак, доставку, запасные детали | | **≈ 725** |

Как сэкономить: клоны модулей MAX98357A вместо Adafruit — около −70 $.
Динамики 32 мм Dayton Audio CE32A-8 (≈ 5–20 $, часто нет в наличии) вместо 28-мм добавят
60–330 $ и заметной разницы в полосе 1.5–4.3 кГц не дадут.

Стоимость собранной распределительной платы — оценка: окончательная цена будет понятна
после разводки в KiCad и расчёта на сайте фабрики.

## Замечания по выбору

* **Colorlight i9** — та же ПЛИС Lattice ECP5, что и у ULX3S (45F вместо 85F), тот же
  генератор 25 МГц и открытый маршрут сборки, но в несколько раз дешевле и доступнее.
  Сравнение с другими платами — в [architecture.md](architecture.md#выбор-платы-плис).
* **MAX98357A**: вход I2S, ЦАП и усилитель класса D на одном модуле, без настройки по I2C.
  В левый и правый слоты подаются одинаковые отсчёты, поэтому режим выбора канала (SD)
  не важен — выводы GAIN и SD просто не подключаются.
* **ICS-43434 на готовом круглом модуле**: микрофон + АЦП 24 бит, выводы VDD, GND, SCK,
  WS, SD, L/R. Модуль ставится в гнездо держателя над динамиком.
* **Динамик — любой массовый круглый 28 мм, 8 Ом, 2 Вт** (такие ставят в Arduino-наборы и
  ноутбуки). Точная модель не важна: рабочая полоса 1.5–4.3 кГц у всех таких динамиков
  ровная, а держатель подстраивается под размеры параметрами (см. [mechanics.md](mechanics.md)).
* **Динамики берите одной партии** и с запасом: разброс чувствительности и фазы между
  экземплярами — главный источник ошибок решётки (лечится калибровкой).
* **Модули с уже запаянными гребёнками** избавляют от пайки совсем; если гребёнки
  приходят отдельно — это 11 выводов на элемент, простая выводная пайка.

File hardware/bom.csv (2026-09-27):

group | ref | item | example_part | qty | unit_usd | notes
core | A1 | Модуль Colorlight i9 v7.2 (LFE5U-45F) + плата расширения (DAPLink USB JTAG/UART, 6 сдвоенных PMOD) | AliExpress, лот «i9 + ext board» | 1 | 60 | проверить, что в лоте есть плата расширения
core | A2 | ESP32-S3-DevKitC-1 (Wi‑Fi-пульт) | Espressif или клон | 1 | 10 | UART к ПЛИС
core | — | USB-UART адаптер CP2102/CH340 3.3 В |  | 1 | 3 | резерв
element | A6.1 | Модуль усилителя MAX98357A (I2S, класс D) | Adafruit #3006 или клон; лучше с запаянной гребёнкой | 18 | 6 | 16 + 2 запасных
element | A6.2 | Модуль микрофона ICS-43434 (I2S, круглый) | маркетплейсы «ICS-43434 модуль» | 20 | 5 | 16 + зонд + 3 запасных
element | BA1 | Динамик круглый 28 мм, 8 Ом, 2 Вт, внутренний магнит | маркетплейсы «28mm 8ohm 2W speaker» (Gikfun AE1054, uxcell и др.) | 18 | 1.5 | одной партии; альтернативы — овальный 15x24 мм 8 Ом 1 Вт, 36 мм майларовый 8 Ом 1 Вт, 32 мм CE32A-8
element | W8–W23 | Провода Dupont F–F 30 и 40 см (ленты по 40 шт.) |  | 6 | 3 | ~180 проводов + запас
element | MECH-E | Печать держателей и крышек (PETG ~0.4 кг), закладные M3, винты M3x8, стяжки | hardware/mech/stl | 1 | 25 | при наличии принтера
hub | A3 | Распределительная плата, собранная на фабрике (SMT + THT; буферы, питание, PCM5102A, TDA1308, разъёмы) | JLCPCB/PCBWay, файлы — после разводки в KiCad | 1 | 90 | оценка: плата + детали + монтаж, партия 2 шт.
hub | BF1, BF2 | Наушники закрытые 32 Ом |  | 2 | 25 | по одним на посетителя
power | G1 | Блок питания 5 В 6 А закрытый | Mean Well GST60A05-P1J | 1 | 20
power | G2 | USB-зарядник 5 В 2 А, 2 порта + 2 кабеля USB-C |  | 1 | 10
cable | W1–W6 | Готовые шлейфы IDC 2x6 (12 pin) 20–30 см |  | 6 | 1.5
probe | A22 | Переходник RJ45 с винтовыми клеммами + патч-корд CAT5 3 м |  | 1 | 6 | модуль микрофона — из A6.2
mech | MECH | Задняя панель (лазерная резка), стойка, ткань, крепёж | hardware/mech/stl/panel_line.svg | 1 | 80
misc | CONS | Расходники (припой, термоусадка, термоклей) |  | 1 | 15

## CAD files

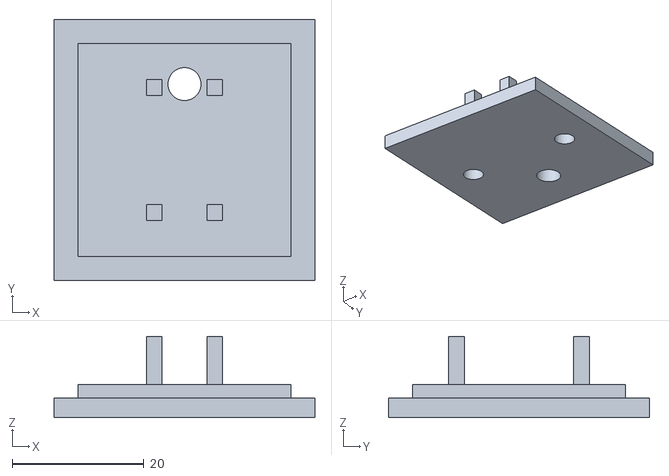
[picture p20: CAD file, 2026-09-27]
hardware/mech/stl/back_ov1524.stl
39.6 x 39.6 x 12.3

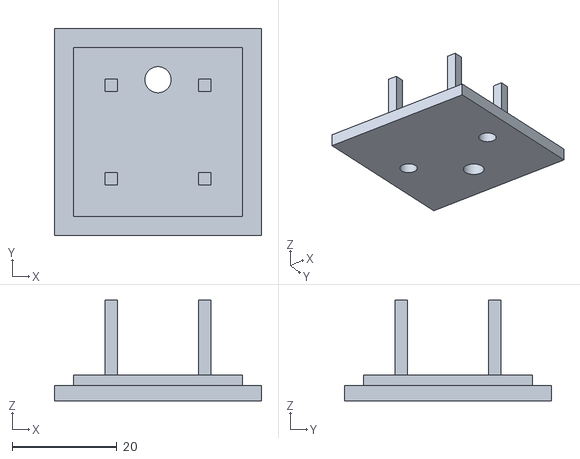
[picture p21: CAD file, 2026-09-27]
hardware/mech/stl/back_rd28.stl
39.6 x 39.6 x 19.3

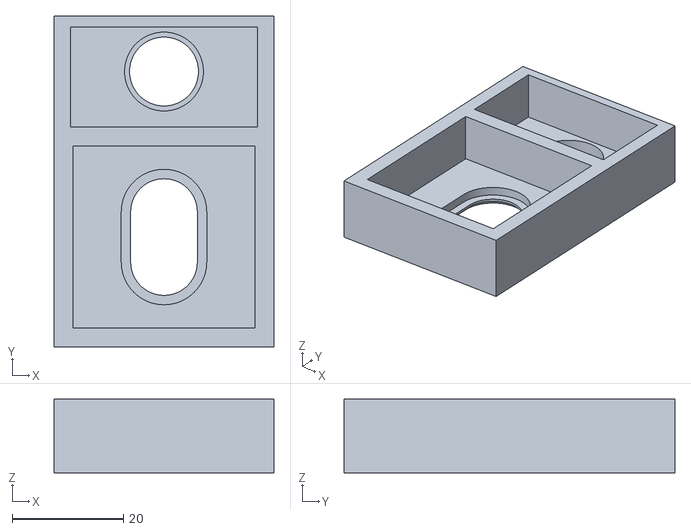
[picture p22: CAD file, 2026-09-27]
hardware/mech/stl/holder_ov1524.stl
39.6 x 59.6 x 13.3

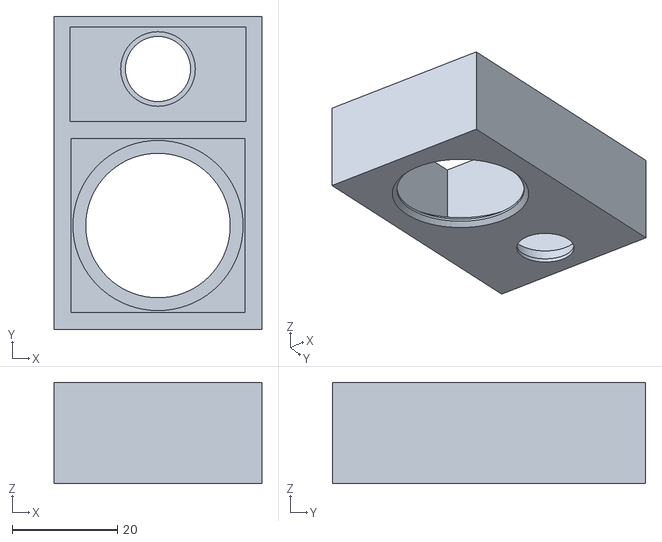
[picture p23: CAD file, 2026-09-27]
hardware/mech/stl/holder_rd32.stl
39.6 x 59.6 x 19.3

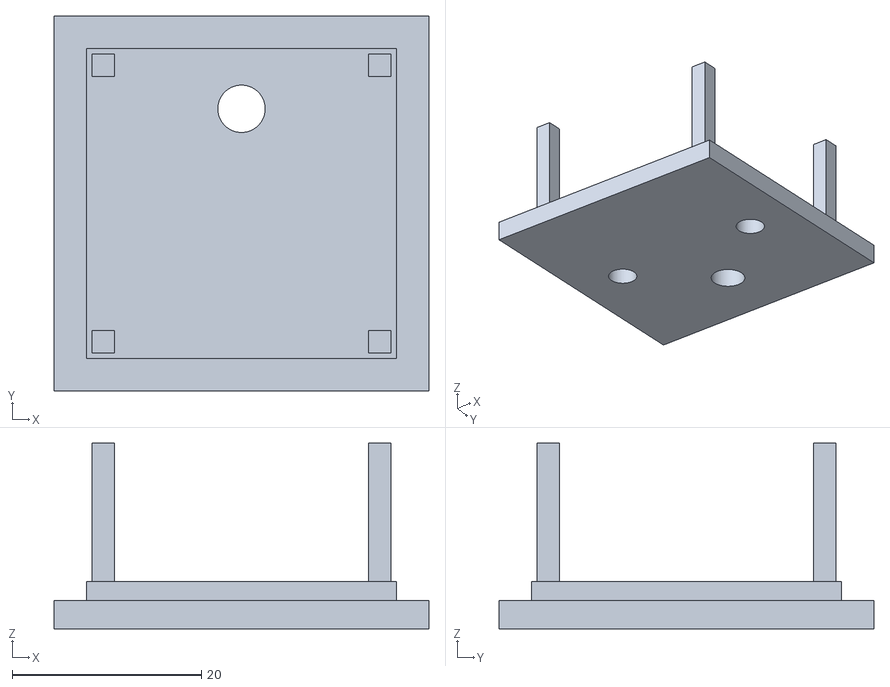
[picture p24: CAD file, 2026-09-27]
hardware/mech/stl/back_sq32.stl
39.6 x 39.6 x 19.6

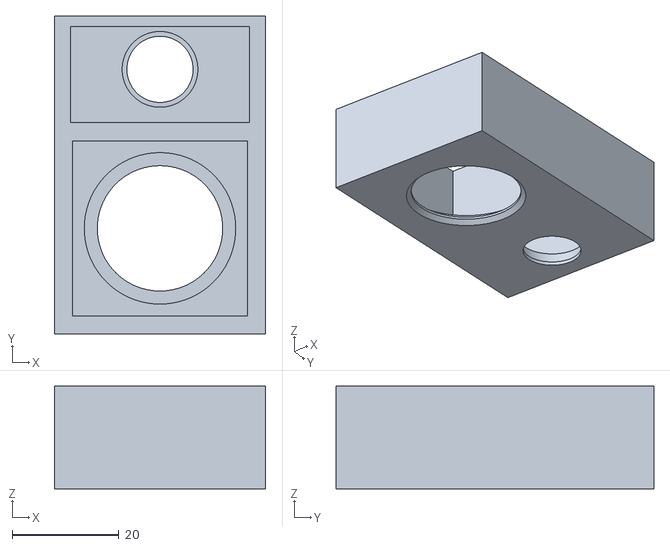
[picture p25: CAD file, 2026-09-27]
hardware/mech/stl/holder_rd28.stl
39.6 x 59.6 x 19.3

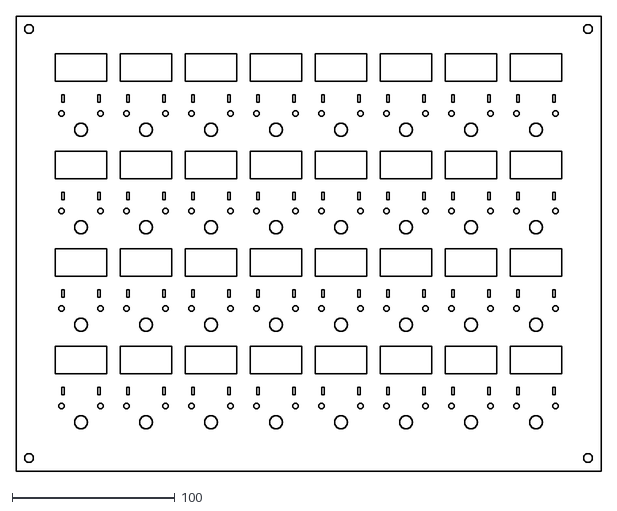
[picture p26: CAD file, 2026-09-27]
hardware/mech/stl/panel_planar.dxf
360.0 x 280.0

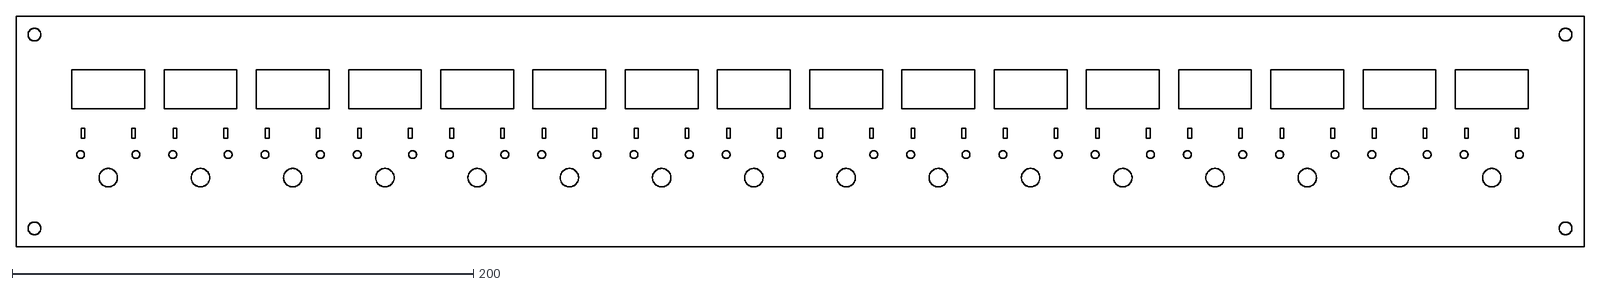
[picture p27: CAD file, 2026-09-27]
hardware/mech/stl/panel_line.dxf
680.0 x 100.0

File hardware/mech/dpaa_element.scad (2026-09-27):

// Держатель элемента акустической ЦАФАР под ГОТОВЫЕ модули (минимум своего монтажа).
//
// «Плитка» 39.6 x 59.6 мм (шаг решётки 40 мм по горизонтали, 60 мм по вертикали):
//   внизу  — динамик (круглый 28…36 мм или овальный 15 x 24 мм) в закрытом объёме;
//   вверху — круглое гнездо под готовый модуль микрофона ICS-43434 (Ø ≈ 14 мм,
//            проверить штангенциркулем и поправить mic_d): модуль вставляется сзади
//            до упорного бортика, выводы смотрят назад, к проводам.
// Модуль усилителя MAX98357A крепится стяжкой к задней панели за динамиком.
//
// Система координат: x — вправо, y — вверх, z — от лицевой плоскости назад.
// Печать: держатель — лицом вниз на стол; крышка — наружной стороной вниз.
// PLA/PETG, сопло 0.4, слой 0.2, 3–4 периметра, заполнение 30 %, без поддержек.
//
// Использование:
//   openscad -D 'part="holder"' -D 'speaker="rd28"' -o holder.stl dpaa_element.scad
//   part: holder | back | assembly | exploded | array_line | array_planar
//         | panel_line | panel_planar (2D, для лазерной резки: экспорт в SVG/DXF)

part    = "exploded";
// Динамик (размеры в таблице ниже — типовые, ИЗМЕРИТЬ свою партию и поправить):
//   "rd28" — круглый 28 мм, 8 Ом 2 Вт, внутренний магнит (основной, ≈ 0.5–1 $);
//   "rd36" — круглый 36 мм майларовый, 8 Ом 1 Вт (самый дешёвый, 1 Вт — см. mechanics.md);
//   "rd32" — круглый 32 мм (Dayton Audio CE32A-8 и аналоги);
//   "sq32" — квадратный 32 мм (Visaton BF 32 S);
//   "ov1524" — овальный 15 x 24 x 3.5 мм, 8 Ом 0.8 Вт (длинной стороной вертикально).
speaker = "rd28";

$fn = 72;

// ---------- решётка ----------
pitch_x = 40;
pitch_y = 60;
gap     = 0.4;
W       = pitch_x - gap;      // ширина плитки
Ht      = pitch_y - gap;      // высота плитки
sp_y    = -Ht/2 + W/2;        // центр динамика (-10)
mic_y   =  Ht/2 - (Ht - W)/2; // центр микрофона (+19.8)

// ---------- динамик ----------
//   [ширина (Ø), высота (= ширине у круглых), монтажная глубина, толщина обода,
//    Ø магнита, глубина объёма за динамиком L_cav]
spk_table = [["rd28",   [28.0, 28.0,  6.0, 1.5, 16, 16]],
             ["rd36",   [36.0, 36.0,  5.0, 1.5, 16, 16]],
             ["rd32",   [32.0, 32.0, 14.5, 1.2, 22, 16]],
             ["sq32",   [32.0, 32.0, 11.0, 1.2, 22, 16]],
             ["ov1524", [15.0, 24.0,  3.5, 2.5, 10, 10]]];  // выводы 50 мм — объём мельче
spk      = spk_table[search([speaker], spk_table)[0]][1];
shape    = speaker[0] == "s" ? "square" : speaker[0] == "o" ? "oval" : "round";
spk_w    = spk[0];
spk_h    = spk[1];
spk_depth= spk[2];            // от лицевой плоскости рамы до торца магнита
flange_t = spk[3];            // толщина обода, на который давят упоры крышки
magnet_d = spk[4];
L_cav    = spk[5];
spk_clr  = 0.4;               // зазор гнезда под раму

// ---------- лицевая часть ----------
lip        = 1.5;             // толщина перед рамой динамика
flange_pkt = 1.8;             // гнездо под раму динамика
t_front    = lip + flange_pkt;
horn_in    = shape == "oval" ? 3.0 : 4.5;   // раскрыв меньше рамы: рама лежит на бортике
chamfer    = 1.0;

// ---------- объём за динамиком ----------
cav    = max(32.8, max(spk_w, spk_h) + 2*spk_clr + 0.4);  // для 36 мм стенки ≈ 1.4 мм
depth  = t_front + L_cav;

// ---------- модуль микрофона ----------
mic_d     = 14.2;             // диаметр гнезда = диаметр модуля + 0.2 (ИЗМЕРИТЬ модуль!)
mic_lip_w = 0.9;              // ширина упорного бортика спереди
mic_lip_t = 0.8;              // толщина бортика
wall      = 3;                // боковые стенки верхней части

// ---------- крышка ----------
back_t  = 3;
plug_h  = 2;
clr     = 0.25;
post    = 2.4;
// упоры давят на обод рамы: у квадратной — в углы, у круглой — по диагоналям на радиусе
// spk_w/2 - 1.3, у овальной — ближе к концам (в середине магнит, внизу провода)
pr      = (spk_w/2 - 1.3) / sqrt(2);
oy      = spk_h/2 - 2.5;
ox      = sqrt(pow(spk_w/2, 2) - pow(oy - (spk_h - spk_w)/2, 2)) - 1.0;
pxy     = shape == "square" ? [14.6, 14.6] : shape == "oval" ? [ox, oy] : [pr, pr];
posts   = [for (sx = [-1, 1], sy = [-1, 1]) [sx*pxy[0], sy*pxy[1]]];
m3_xy   = 12;
m3_d    = 4.2;
cable_d = 5;
cable_y = -10;                // относительно центра динамика

// =====================================================================
// контур рамы динамика (2D), увеличенный на grow с каждой стороны
module spk_outline(grow = 0) {
    w = spk_w + 2*grow;
    h = spk_h + 2*grow;
    if (shape == "square") square([w, h], center = true);
    else hull() for (sy = [-1, 1]) translate([0, sy*(h - w)/2]) circle(d = w);
}

// раскрыв: у квадратной рамы — круглый (диффузор круглый)
module horn_outline(grow = 0) {
    if (shape == "square") circle(d = spk_w + 2*grow);
    else spk_outline(grow);
}

module holder() {
    difference() {
        union() {
            translate([-W/2, -Ht/2, 0]) cube([W, Ht, t_front]);                        // лицевая пластина
            translate([-W/2, sp_y - W/2, 0]) cube([W, W, depth]);                       // корпус динамика
            for (sx = [-1, 1])                                                          // стенки верхней части
                translate([sx > 0 ? W/2 - wall : -W/2, sp_y + W/2 - 1, 0]) cube([wall, Ht - W + 1, depth]);
            translate([-W/2, Ht/2 - 2, 0]) cube([W, 2, depth]);                         // верхняя кромка
        }
        // объём за динамиком
        translate([-cav/2, sp_y - cav/2, t_front]) cube([cav, cav, L_cav + 1]);
        // гнездо под раму динамика
        translate([0, sp_y, lip]) linear_extrude(flange_pkt + 0.01) spk_outline(spk_clr/2);
        // раскрыв с фаской
        translate([0, sp_y, -1]) linear_extrude(t_front + 2) horn_outline(-horn_in/2);
        translate([0, sp_y, -0.01]) hull() {
            linear_extrude(0.01) horn_outline(-horn_in/2 + chamfer);
            translate([0, 0, chamfer]) linear_extrude(0.01) horn_outline(-horn_in/2);
        }
        // гнездо микрофона: сквозное отверстие с упорным бортиком спереди
        translate([0, mic_y, mic_lip_t]) cylinder(d = mic_d, h = depth);
        translate([0, mic_y, -1]) cylinder(d = mic_d - 2*mic_lip_w, h = mic_lip_t + 2);
    }
}

module back() {
    difference() {
        union() {
            translate([-W/2, -W/2, 0]) cube([W, W, back_t]);
            translate([-(cav - 2*clr)/2, -(cav - 2*clr)/2, -plug_h]) cube([cav - 2*clr, cav - 2*clr, plug_h]);
            post_len = depth - plug_h - (lip + flange_t);
            for (q = posts)
                translate([q[0] - post/2, q[1] - post/2, -plug_h - post_len])
                    cube([post, post, post_len]);
        }
        // глухие закладные M3 — объём остаётся герметичным
        for (sx = [-1, 1]) translate([sx*m3_xy, 0, -plug_h + 0.8]) cylinder(d = m3_d, h = back_t + plug_h);
        // провода динамика (после монтажа залить термоклеем)
        translate([0, cable_y, -plug_h - 1]) cylinder(d = cable_d, h = back_t + plug_h + 2);
    }
}

// условные модели готовых модулей и динамика для сборочных видов
module speaker_dummy() {
    basket = max(0, min(3, spk_depth - flange_t - 1));
    color(shape == "oval" ? "white" : "dimgray") {
        linear_extrude(flange_t) spk_outline();
        if (basket > 0)
            translate([0, 0, flange_t]) cylinder(d1 = min(spk_w, spk_h) - 4, d2 = magnet_d, h = basket);
        translate([0, 0, flange_t + basket]) cylinder(d = magnet_d, h = spk_depth - flange_t - basket);
    }
    color("black") translate([0, 0, -0.01]) linear_extrude(0.2) spk_outline(-2);
}

module mic_module_dummy() {       // круглая плата Ø14 с двумя рядами по 3 штыря
    color("black") cylinder(d = mic_d - 0.2, h = 1.6);
    color("silver") translate([-1.75, -1.3, 1.6]) cube([3.5, 2.6, 1]);
    for (sx = [-1, 1], i = [-1:1])
        color("gold") translate([sx*4.5, i*2.54, 1.6]) cylinder(d = 0.64, h = 8, $fn = 8);
}

module amp_module_dummy() {       // модуль MAX98357A ~18 x 19 мм
    color("royalblue") translate([-9, -9.5, 0]) cube([18, 19, 1.6]);
    color("black") translate([-1.5, -1.5, 1.6]) cube([3, 3, 0.8]);
}

module element(explode = 0) {
    color("lightsteelblue") holder();
    translate([0, sp_y, lip + explode*1.6]) speaker_dummy();
    translate([0, mic_y, mic_lip_t + explode*1.0]) mic_module_dummy();
    color("slategray") translate([0, sp_y, depth + explode*2.2]) back();
    translate([0, sp_y + 2, depth + back_t + 4 + explode*3.2]) amp_module_dummy();   // на задней панели
}
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

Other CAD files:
hardware/mech/stl/back_rd36.stl
hardware/mech/stl/holder_rd36.stl
hardware/mech/stl/holder_sq32.stl
hardware/mech/stl/back_rd32.stl
hardware/mech/stl/holder_square32.stl
hardware/mech/stl/back_square32.stl
hardware/mech/stl/back_round32.stl
hardware/mech/stl/holder_round32.stl

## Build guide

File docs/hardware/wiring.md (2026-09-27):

# Схема соединений

Уровень устройств: какие платы и модули есть в установке, какими разъёмами они
соединяются и какими кабелями. Внутреннее устройство плат — в [schematics.md](schematics.md),
функциональная (структурная) схема — в [architecture.md](architecture.md).

Схема соединений

Исходник рисунка — `scripts/draw_wiring_diagram.py` (PNG для печати: `docs/img/wiring.png`).

## Перечень устройств

| Поз. | Наименование | Кол-во | Разъёмы |
|---|---|---|---|
| A1 | Плата ПЛИС: Colorlight i9 (LFE5U-45F) + плата расширения с DAPLink | 1 | XS1 USB-C; P1–P6 — сдвоенные PMOD 2×6 |
| A2 | ESP32-S3 DevKitC-1 (Wi‑Fi-пульт) | 1 | USB-C; штыревая гребёнка |
| A3 | Распределительная плата (своя, собирается фабрикой; на ней ЦАП PCM5102A и драйвер наушников TDA1308) | 1 | J1–J16 штыревые 2×6 (элементы); J17 RJ45 (зонд); J18 питание 5 В; J19–J24 PMOD 2×6 (к A1); J25 3 конт. (ESP32); J26, J27 гнёзда 3.5 мм (наушники); J28 3 конт. (резервный UART) |
| A6–A21 | Элемент решётки № 1–16 (в 3D-печатном держателе) | 16 | — |
| A6.1 … | готовый модуль усилителя MAX98357A | 16 | гребёнка: VIN, GND, BCLK, LRC, DIN; выход на динамик |
| A6.2 … | готовый модуль микрофона ICS-43434 | 16 | гребёнка: VDD, GND, SCK, WS, SD, L/R |
| BA1 … | Динамик 28 мм 8 Ом 2 Вт | 16 | 2 провода |
| A22 | Калибровочный зонд: готовый модуль ICS-43434 + готовый переходник RJ45 с винтовыми клеммами | 1 | XS1 RJ45 |
| G1 | Блок питания 5 В 6 А | 1 | штекер 5.5/2.1 мм |
| G2 | USB-зарядник 5 В 2 А, 2 порта (при отладке — ноутбук) | 1 | USB-A / USB-C |
| BF1, BF2 | Наушники | 2 | штекер 3.5 мм |

## Перечень кабелей

| Обозн. | Откуда | Куда | Тип | Жил | Длина | Сигналы |
|---|---|---|---|---|---|---|
| W1–W6 | A1: P1–P6 | A3: J19–J24 | шлейф IDC 2×6, прямой (контакт n → n) | 12 | 0.3 м | раскладка ниже |
| W7 | A3: J25 | A2: гребёнка | провода Dupont | 3 | 0.2 м | UART TX, RX, GND |
| W8–W23 | A3: J1–J16 | A6.1, A6.2 элемента n | провода Dupont F–F (жгут) | 11 | 30–40 см | 5 проводов к усилителю, 6 к микрофону — [pinout.md](pinout.md) |
| W24 | A3: J17 | A22: XS1 | CAT5, RJ45 (T568B) | 8 | 3 м | BCLK, LRCLK, SD, 3.3 В, GND |
| W25 | G1 | A3: J18 | шнур DC 5.5/2.1 мм | 2 | 1.5 м | +5 В, GND (до 5 А) |
| W26 | G2 или ноутбук | A1: XS1 | USB-C | — | 1 м | питание A1; JTAG и UART через DAPLink |
| W27 | G2 | A2: USB | USB-C | — | 1 м | питание A2 |
| — | A6.1: OUT± | BA1 | провод 0.35 мм² | 2 | 0.1 м | выход усилителя |
| — | XS1 зонда (клеммы) | A22: модуль | провода Dupont | 6 | 0.1 м | VDD, GND, SCK, WS, SD, L/R |
| — | A3: J26, J27 | BF1, BF2 | штекер 3.5 мм | 3 | — | левое ухо — луч приёма 0, правое — луч 1 |
| (W28) | A3: J28 | адаптер CP2102 | провода Dupont | 3 | 0.2 м | резерв: UART к ноутбуку, если UART DAPLink не выведен на ПЛИС |

## Раскладка сигналов по кабелям W1–W6 (PMOD 2×6)

Нумерация контактов — как у PMOD: 1–6 верхний ряд, 7–12 нижний; 5 и 11 — GND,
6 и 12 — 3.3 В. **Контакты 3.3 В на распределительной плате не подключаются**: у A3 свой
стабилизатор U20, а земли соединяются все. Направление указано относительно ПЛИС.

| Кабель | A1 → A3 | 1 | 2 | 3 | 4 | 7 | 8 | 9 | 10 |
|---|---|---|---|---|---|---|---|---|---|
| W1 | P1 → J19 | BCLK → | LRCLK → | MON_SD → | ← BTN_TEST | ESP_TX → | ← ESP_RX | USB_TX → | ← USB_RX |
| W2 | P2 → J20 | TXD0 → | TXD1 → | TXD2 → | TXD3 → | TXD4 → | TXD5 → | TXD6 → | TXD7 → |
| W3 | P3 → J21 | TXD8 → | TXD9 → | TXD10 → | TXD11 → | TXD12 → | TXD13 → | TXD14 → | TXD15 → |
| W4 | P4 → J22 | ← MIC0 | ← MIC1 | ← MIC2 | ← MIC3 | ← MIC4 | ← MIC5 | ← MIC6 | ← MIC7 |
| W5 | P5 → J23 | ← MIC8 | ← MIC9 | ← MIC10 | ← MIC11 | ← MIC12 | ← MIC13 | ← MIC14 | ← MIC15 |
| W6 | P6 → J24 | ← CAL | резерв | резерв | резерв | резерв | резерв | резерв | резерв |

Резерв на P6 (7 линий) и свободные PMOD платы расширения пригодятся при переходе на
плоскую решётку 8 × 4.

На распределительной плате: BCLK, LRCLK — на буферы 74LVC244 U1–U8 (свой выход на каждый
модуль), TXD — на U9, U10; MIC0–15 — с выходов буферов U11, U12 через 33 Ом; MON_SD — на
ЦАП U31 через U13; CAL — с разъёма J17 через U13; ESP_TX/ESP_RX — на J25 через 100 Ом; USB_TX/USB_RX — на J28
через 100 Ом; BTN_TEST — кнопка SW1 на 3.3 В (подтяжка к земле включена в ПЛИС).

## Разъёмы распределительной платы для вспомогательных кабелей

| Разъём | Контакт | Сигнал | Примечание |
|---|---|---|---|
| J25 (к ESP32) | 1 | ESP_TX (ПЛИС → ESP32 RX) | на ESP32 — вывод RX UART1, например GPIO18; задаётся в прошивке пульта |
| | 2 | ESP_RX (ESP32 TX → ПЛИС) | на ESP32 — вывод TX UART1, например GPIO17 |
| | 3 | GND | |
| J28 (резерв) | 1 | USB_TX (ПЛИС → RX адаптера) | адаптер CP2102/CH340 на 3.3 В |
| | 2 | USB_RX (TX адаптера → ПЛИС) | |
| | 3 | GND | |
| J18 | +, − | +5 В, GND | гнездо 5.5/2.1 мм, центр — «+» |

Раскладка проводов W8–W23 (разъём 2×6) и кабеля зонда W24 (RJ45) — в [pinout.md](pinout.md).

## Порядок подключения

1. Всё собрать и соединить **при выключенном питании**; ключи всех разъёмов IDC —
   в одну сторону.
2. Включить G2 (плата ПЛИС и ESP32), загрузить прошивку ПЛИС (`make prog`),
   проверить `dpaa_ctl.py id`.
3. Только после этого включить G1 (питание элементов). Выключать в обратном порядке.

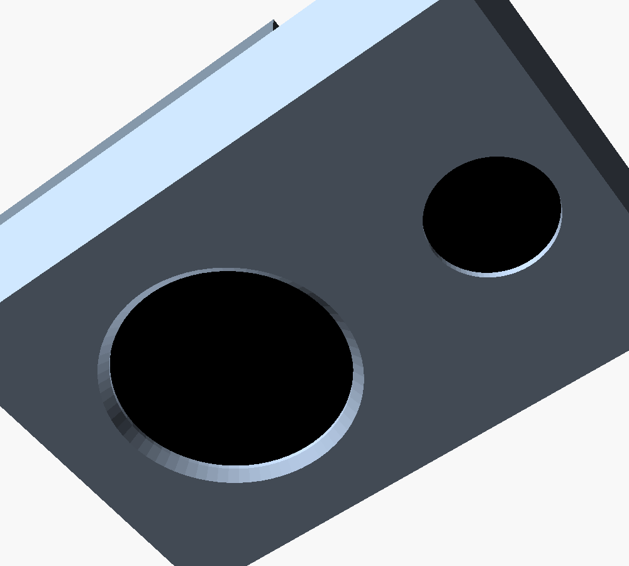
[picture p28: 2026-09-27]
hardware/mech/render/assembly.png

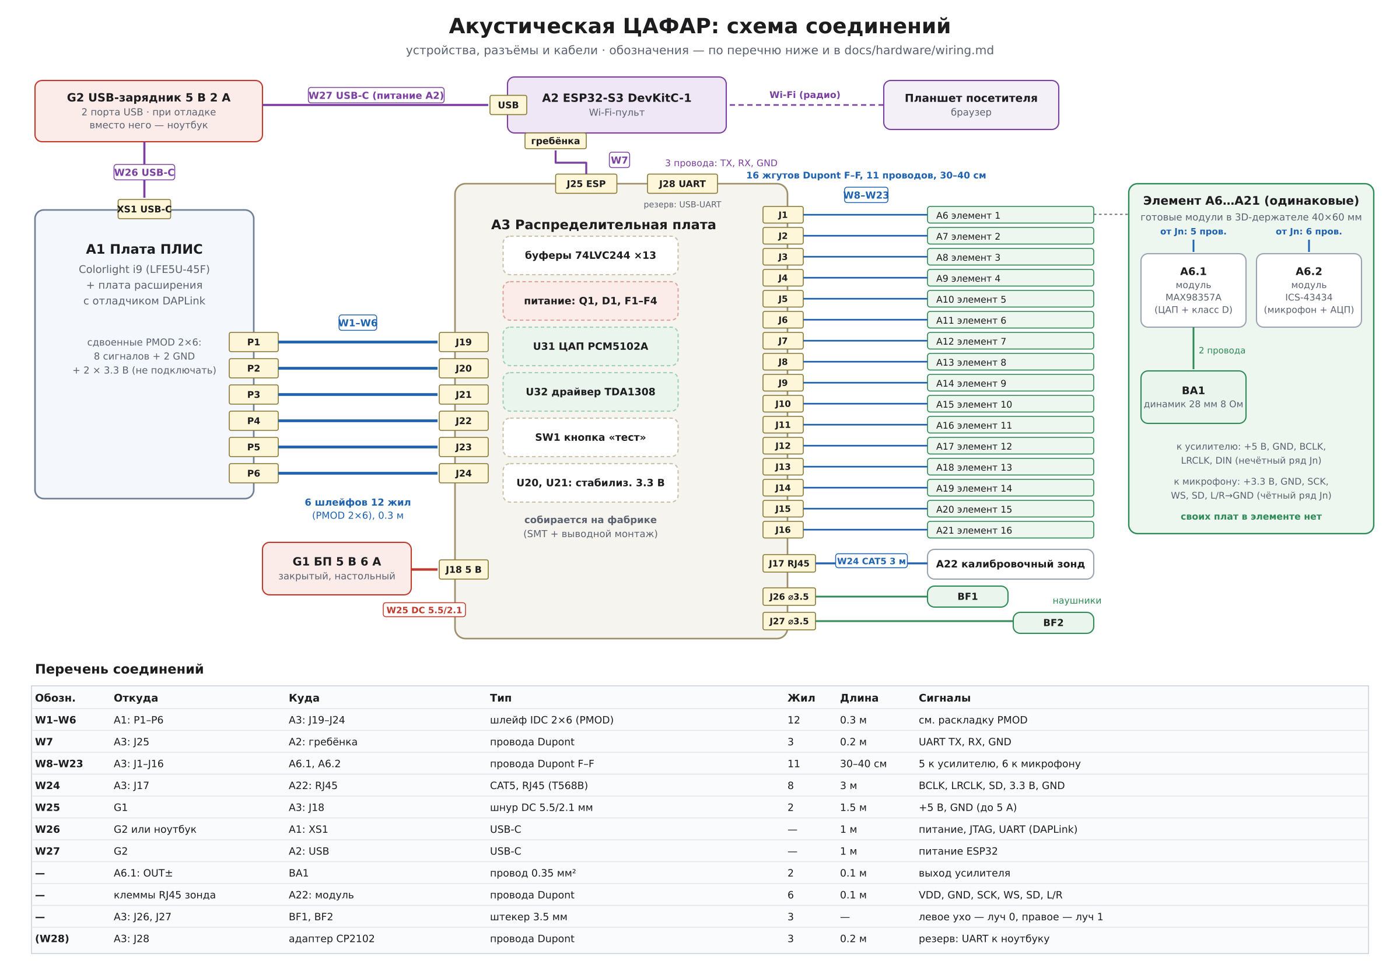
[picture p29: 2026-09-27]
docs/img/wiring.png

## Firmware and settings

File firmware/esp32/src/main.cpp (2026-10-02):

// Wi-Fi-пульт акустической ЦАФАР на ESP32-S3-DevKitC-1.
//
//   планшет --Wi-Fi--> ESP32 (точка доступа, веб-страница) --UART1 1 Мбит/с--> ПЛИС
//
// Вся логика — в lib/dpaa (контроллер и ядро, проверены на компьютере против Python-модели),
// здесь только «железо»: UART, Wi-Fi, веб-сервер, хранение настроек.
//
// Подключение к распределительной плате (разъём J25, docs/hardware/wiring.md):
//   GPIO17 (TX UART1) -> J25.2 -> ПЛИС esp_rx;   GPIO18 (RX UART1) <- J25.1 <- ПЛИС esp_tx;   GND -> J25.3
#include <Arduino.h>
#include <DNSServer.h>
#include <ESPmDNS.h>
#include <Preferences.h>
#include <WebServer.h>
#include <WiFi.h>

#include "controller.h"
#include "web_page.h"

namespace {

constexpr int kUartTx = 17;
constexpr int kUartRx = 18;
constexpr uint32_t kUartBaud = 1000000;
constexpr uint32_t kReadTimeoutUs = 3000;      // ответ ПЛИС приходит через ~0.2 мс
constexpr uint32_t kSaveDelayMs = 3000;        // настройки пишем во флеш не чаще, чем раз в 3 с
const char* const kDefaultSsid = "DPAA";
const char* const kDefaultPass = "dpaa2026";   // не короче 8 символов (требование WPA2)
const IPAddress kIp(192, 168, 4, 1);

/// Канал к ПЛИС через UART1. ПЛИС отвечает сразу в оба порта (ноутбуку и ESP32),
/// поэтому перед чтением входной буфер очищается, а ответ проверяется по адресу.
class UartLink : public dpaa::Link {
 public:
  explicit UartLink(HardwareSerial& s) : s_(s) {}

  void send(const dpaa::Frames& frames) override {
    for (const dpaa::Frame& f : frames) s_.write(f.b, dpaa::kFrameLen);
  }

  bool read(int addr, int32_t& value) override {
    while (s_.available()) s_.read();
    const dpaa::Frame req = dpaa::encode_read(addr);
    s_.write(req.b, dpaa::kFrameLen);
    uint8_t buf[dpaa::kFrameLen];
    int n = 0;
    const uint32_t t0 = micros();
    while (micros() - t0 < kReadTimeoutUs) {
      if (!s_.available()) continue;
      const uint8_t b = uint8_t(s_.read());
      if (n == 0 && b != 0x5A) continue;        // ждём начало кадра ответа
      buf[n++] = b;
      if (n == dpaa::kFrameLen) {
        int a = 0;
        int32_t d = 0;
        if (dpaa::decode_response(buf, a, d) && a == addr) {
          value = d;
          return true;
        }
        n = 0;                                  // чужой или повреждённый ответ — ищем дальше
      }
    }
    return false;
  }

 private:
  HardwareSerial& s_;
};

UartLink link(Serial1);
dpaa::Controller ctl(link);
WebServer server(80);
DNSServer dns;
Preferences prefs;
uint32_t settings_changed_at = 0;
bool settings_pending = false;

void load_settings() {
  prefs.begin("dpaa", true);
  dpaa::Settings& s = ctl.settings();
  s.max_amp = prefs.getFloat("maxamp", float(s.max_amp));
  s.demo = prefs.getBool("demo", s.demo);
  s.demo_idle_s = prefs.getUInt("idle", s.demo_idle_s);
  prefs.end();
}

void save_settings() {
  prefs.begin("dpaa", false);
  const dpaa::Settings& s = ctl.settings();
  prefs.putFloat("maxamp", float(s.max_amp));
  prefs.putBool("demo", s.demo);
  prefs.putUInt("idle", s.demo_idle_s);
  prefs.end();
}

void handle_api() {
  dpaa::Query q;
  for (int i = 0; i < server.args(); i++) q[server.argName(i).c_str()] = server.arg(i).c_str();
  const std::string json = ctl.handle(server.uri().c_str(), q, millis());
  server.sendHeader("Cache-Control", "no-store");
  server.send(200, "application/json; charset=utf-8", json.c_str());
}

void handle_page() {
  server.sendHeader("Content-Encoding", "gzip");
  server.sendHeader("Cache-Control", "no-cache");
  server.send_P(200, "text/html; charset=utf-8", reinterpret_cast<const char*>(WEB_PAGE_GZ), WEB_PAGE_GZ_LEN);
}

/// Смена имени и пароля сети: /api/wifi?ssid=...&pass=... (пароль от 8 символов), затем перезагрузка.
void handle_wifi() {
  const String ssid = server.arg("ssid"), pass = server.arg("pass");
  if (ssid.length() == 0 || ssid.length() > 32 || pass.length() < 8 || pass.length() > 63) {
    server.send(400, "text/plain; charset=utf-8", "нужны ssid (1-32 символа) и pass (8-63 символа)");
    return;
  }
  prefs.begin("dpaa", false);
  prefs.putString("ssid", ssid);
  prefs.putString("pass", pass);
  prefs.end();
  server.send(200, "text/plain; charset=utf-8", "сохранено, перезагрузка");
  delay(300);
  ESP.restart();
}

/// Любой другой адрес (проверки «есть ли интернет» телефонов и планшетов) — на страницу пульта:
/// так при подключении к сети страница открывается сама.
void handle_other() {
  server.sendHeader("Location", String("http://") + kIp.toString() + "/");
  server.send(302, "text/plain", "");
}

}  // namespace

void setup() {
  Serial.begin(115200);
  Serial1.setRxBufferSize(256);
  Serial1.setTxBufferSize(1024);                // таблица луча (≈ 560 байт) уходит без ожидания
  Serial1.begin(kUartBaud, SERIAL_8N1, kUartRx, kUartTx);

  load_settings();
  prefs.begin("dpaa", true);
  const String ssid = prefs.getString("ssid", kDefaultSsid);
  const String pass = prefs.getString("pass", kDefaultPass);
  prefs.end();

  WiFi.mode(WIFI_AP);
  WiFi.softAPConfig(kIp, kIp, IPAddress(255, 255, 255, 0));
  WiFi.softAP(ssid.c_str(), pass.c_str(), 6, 0, 8);
  WiFi.setSleep(false);                         // без энергосбережения — меньше задержка «руля»
  dns.start(53, "*", kIp);
  MDNS.begin("dpaa");                           // http://dpaa.local/
  MDNS.addService("http", "tcp", 80);

  server.on("/", HTTP_GET, handle_page);
  server.on("/api/state", HTTP_GET, handle_api);
  server.on("/api/set", HTTP_GET, handle_api);
  server.on("/api/stop", HTTP_GET, handle_api);
  server.on("/api/wifi", HTTP_GET, handle_wifi);
  server.onNotFound(handle_other);
  server.begin();

  ctl.handle("/api/stop", dpaa::Query(), millis());   // после включения — тишина
  Serial.printf("DPAA: Wi-Fi \"%s\", http://%s/ или http://dpaa.local/\n", ssid.c_str(), kIp.toString().c_str());
}

void loop() {
  dns.processNextRequest();
  server.handleClient();
  ctl.tick(millis());
  if (ctl.take_settings_dirty()) {
    settings_pending = true;
    settings_changed_at = millis();
  }
  if (settings_pending && millis() - settings_changed_at >= kSaveDelayMs) {
    settings_pending = false;
    save_settings();
  }
}

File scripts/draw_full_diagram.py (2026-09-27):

"""Полная структурная схема установки (без сокращений и объединений) -> docs/img/full_diagram.svg.

Показано всё: 16 элементов по отдельности, все буферы распределительной платы,
все блоки прошивки ПЛИС, питание, кабели и разъёмы с позиционными обозначениями.

Запуск:  python scripts/draw_full_diagram.py
PNG:     rsvg-convert -w 3600 docs/img/full_diagram.svg -o docs/img/full_diagram.png
"""
import sys
from pathlib import Path

sys.path.insert(0, str(Path(__file__).resolve().parent))
from svgdraw import C, FILL, box, header, label, out, save, text, wire  # noqa: E402

C["gnd"] = "#3a3a3a"
OUT = Path(__file__).resolve().parents[1] / "docs" / "img" / "full_diagram.svg"
W, H = 3560, 2110
CONN = "#fdf6d8"

# ---------------- геометрия ----------------
ROW0, PITCH, ROWH = 318, 64, 54          # строки элементов
N = 16
FX0, FX1 = 490, 1420                     # ПЛИС
c1, c2, c3, c4 = (525, 705), (740, 935), (965, 1165), (1195, 1390)
PX = (1470, 1570)                        # разъёмы PMOD на плате расширения
A3X = (1700, 2500)                       # распределительная плата
JX = (1712, 1792)                        # разъёмы J19–J24 (вход с ПЛИС)
UX = (1880, 2040)                        # буферы
JNX = (2330, 2440)                       # разъёмы J1–J16
EX = (2580, 3400)                        # элементы


def row_y(n):                            # верх строки элемента n = 1…16
    return ROW0 + (n - 1) * PITCH


def conn(x, y, w, h, name, lines=(), size=11):
    out.append(f'<rect x="{x}" y="{y}" width="{w}" height="{h}" rx="2" fill="{CONN}" '
               f'stroke="#8a7a3a" stroke-width="1.1"/>')
    n = len(lines) + 1
    cy = y + h / 2 - (n - 1) * size * 0.65 + size * 0.36
    text(x + w / 2, cy, name, size, "bold")
    for s in lines:
        cy += size * 1.3
        text(x + w / 2, cy, s, size * 0.86, color=C["muted"])


def small(x, y, s, color=None, size=10, anchor="start", weight="normal"):
    text(x, y, s, size, weight, color or C["muted"], anchor)


def blk(xr, y0, y1, title, lines, fill=None, stroke=None, size=10.5, ts=12):
    box(xr[0], y0, xr[1] - xr[0], y1 - y0, title, lines, fill or FILL["blk"], stroke or "#9aa3b0",
        rx=6, size=size, title_size=ts)


def dot(x, y, color):
    out.append(f'<circle cx="{x}" cy="{y}" r="2.6" fill="{color}"/>')


def w(pts, color, width=1.6, **kw):
    wire(pts, color, width, **kw)


def draw():
    header(W, H)
    text(W / 2, 44, "Акустическая цифровая активная фазированная антенная решётка — полная структурная схема установки",
         26, "bold")
    text(W / 2, 74, "16 приёмопередающих элементов · программируемая логическая интегральная схема Lattice ECP5 "
         "LFE5U-45F · шаг решётки 40 мм · рабочая полоса 1.5–4.3 кГц · частота дискретизации 48 828.125 Гц",
         15, color=C["muted"])
    text(W / 2, 96, "все каналы, буферы, блоки прошивки, цепи питания и кабели показаны по отдельности; "
         "расшифровка всех обозначений — в таблице внизу", 13, color=C["muted"])

    # ================= левая колонка: пользователи и управление =================
    box(40, 150, 380, 250, None, (), FILL["user"], C["ctrl"], rx=8)
    text(230, 178, "Ноутбук (отладка и управление)", 15, "bold")
    for i, s in enumerate(["tools/dpaa_ctl.py — лучи, сканирование, фокус,",
                           "   амплитудное распределение, два луча,",
                           "   поэлементный тест, уровни микрофонов",
                           "openFPGALoader — загрузка прошивки ПЛИС",
                           "   (make prog / make flash)",
                           "Python-модель dpaa/ — расчёт и моделирование",
                           "Yosys + nextpnr-ecp5 — сборка прошивки",
                           "USB-C: отладчик DAPLink платы расширения"]):
        small(58, 206 + i * 22, s, C["text"], 12)

    box(40, 470, 380, 90, "Планшет посетителя", ["браузер: кнопки сценариев,", "«руль» направления луча"],
        FILL["user"], C["ctrl"], size=12, title_size=14)
    box(40, 620, 380, 300, None, (), FILL["esp"], C["ctrl"], rx=8)
    text(230, 648, "A2  ESP32-S3-DevKitC-1 (Wi-Fi-пульт)", 14, "bold")
    for i, (t, d) in enumerate([("Точка доступа Wi-Fi", "подключение планшета"),
                                ("Веб-сервер пульта", "страница с кнопками и «рулём»"),
                                ("Расчёт задержек и весов", "те же формулы, что в dpaa/hw.py"),
                                ("Последовательный порт UART1", "1 Мбит/с: GPIO17 — передача, GPIO18 — приём"),
                                ("Разъём USB-C", "питание 5 В и прошивка ESP32")]):
        box(60, 664 + i * 50, 340, 44, t, [d], "#ffffff", "#b9a6cc", rx=5, size=10.5, title_size=11.5)
    w([(230, 560), (230, 616)], C["ctrl"], 1.8, dash="6 4", arrow_start=True)
    label(300, 592, "Wi-Fi (радио)", C["ctrl"], 11)

    box(40, 1010, 380, 90, "G2  USB-зарядное устройство 5 В 2 А",
        ["2 порта; при отладке вместо него — ноутбук"], FILL["pwr"], C["pwr"], size=11.5, title_size=13)
    w([(150, 1010), (150, 920)], C["pwr"], 2)
    label(150, 968, "W27 USB-C", C["pwr"], 11)
    w([(330, 1010), (330, 980), (438, 980), (438, 256), (500, 256)], C["pwr"], 2)
    label(330, 968, "W26 USB-C (в режиме экспоната)", C["pwr"], 11)
    w([(420, 240), (500, 240)], C["ctrl"], 2)
    label(462, 226, "W26", C["ctrl"], 10)

    box(40, 1160, 380, 80, "Адаптер USB-UART CP2102 (резерв)",
        ["3.3 В; нужен, если UART отладчика", "не выведен на выводы ПЛИС"], "#ffffff", C["ctrl"],
        size=11, title_size=12.5, dash="5 4")
    w([(40, 1200), (24, 1200), (24, 300), (40, 300)], C["ctrl"], 1.6, dash="5 4", arrow_end=False)
    text(18, 760, "USB к ноутбуку (резерв)", 10, "bold", C["ctrl"], "middle",
         'transform="rotate(-90 18 760)"')

    # ================= A1: плата ПЛИС =================
    box(450, 150, 1150, 1330, None, (), FILL["board"], "#6f7f95", rx=10, lw=1.8)
    text(1025, 176, "A1  Плата расширения Colorlight i9 (отладчик DAPLink, 6 сдвоенных разъёмов PMOD) "
         "с установленным модулем Colorlight i9 v7.2", 14, "bold")
    box(520, 200, 430, 72, "Отладчик DAPLink (на плате расширения)",
        ["JTAG — загрузка прошивки; UART — если выведен на ПЛИС,", "иначе — резервный адаптер через P1 и J28"],
        "#ffffff", C["ctrl"], size=10.5, title_size=12)
    conn(500, 228, 26, 36, "", ())
    small(513, 222, "XS1", C["text"], 9, "middle", "bold")
    box(980, 200, 420, 72, "Стабилизаторы платы расширения и модуля",
        ["5 В от USB-C → 3.3 В, 2.5 В, 1.1 В для ПЛИС"], "#ffffff", C["pwr"], size=10.5, title_size=12)
    w([(735, 272), (735, 300)], C["ctrl"], 1.8)
    label(790, 290, "JTAG", C["ctrl"], 10.5)
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

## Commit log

2026-09-25 Acoustic DPAA: concept, simulation library and demos
    Concept document for demonstrating digital phased array principles with
    sound (8 speakers/mics, 4 cm pitch, 1.5-4.3 kHz), a small simulation
    library (steering, fractional delays, patterns, TX multi-beam and
    scanning, RX delay-and-sum / MVDR / spatial spectrum), demo scripts that
    produce 8-channel WAVs for a real array plus "virtual listener" WAVs,
    illustrations and tests.
    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
2026-09-25 Hardware design: 16-element FPGA array, BOM and board schematics
    Architecture for a standalone exhibit: ULX3S (ECP5-85F + ESP32), 16
    "T/R modules" each with an I2S class-D amplifier (MAX98357A), speaker
    and I2S MEMS microphone, a buffered distribution board, headphone
    monitor DAC and a calibration probe. Includes BOM (~$714, ~$820 with
    15% reserve), netlist-level schematics, pinout and bring-up plan.
    Claude-Session: https://claude.ai/code/session_01J49skVVek1mWTAjvS5Dt8X
    [bom.csv]
2026-09-25 FPGA gateware: I2S array I/O, signal generators, TX/RX beamforming
    Verilog for ECP5: common-clock I2S for 16 amplifiers and 17 microphones,
    two DDS/noise/chirp generators, a fractional-delay delay-and-sum engine
    (8-tap LS filters, 1/32-sample resolution) used for 2 TX beams and 2 RX
    beams, UART register interface, level meters. Python hardware model
    (register map, protocol, bit-exact engine model), laptop control tool,
    and Icarus Verilog tests that match the RTL against the model bit for
    bit. Synthesis for LFE5U-85F: 17% LUT, Fmax ~60 MHz at 50 MHz.
    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
    [dpaa_ctl.py]
2026-09-25 Amplitude taper, custom weights and element-off for TX/RX beams
    hw.element_weights builds uniform/Taylor/Chebyshev/Hann tapers, custom
    (signed) weights and switched-off elements; tx/rx beam command helpers
    and dpaa_ctl.py expose them (--taper, --sll, --weights, --off). Tests
    decode the command frames and check sidelobe levels with the quantized
    FPGA weights and a difference-pattern null.
    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
2026-09-25 Element holder: speaker + ICS-43434 mic in one 3D-printed 40 mm tile
    Transducer selection (Dayton CE32A-8 main, Visaton BF 32 S premium,
    TDK ICS-43434 on an 8x8 mm factory-assembled micro-board), parametric
    OpenSCAD holder (sealed back volume, flush mic recess, cover with
    speaker clamps, M3 inserts and amplifier-board slot) that tiles at the
    40 mm pitch for both 16x1 and planar arrays; STL files, laser-cut back
    panels (SVG/DXF) and renders. RX beam geometry now includes the mic
    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
    [back_round32.stl, back_square32.stl, bom.csv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]
2026-09-25 Gateware: Colorlight i9 target, banked BRAM beam tables, mono I2S TX
    - top_colorlight_i9.v + LPF template (ECP5 LFE5U-45F, 25 MHz clock,
    UART to ESP32-S3 and laptop); Makefile builds BOARD=i9 (default) or
    BOARD=ulx3s, refuses bitstreams while the LPF has "???" placeholders,
    uses router2.
    - delay_sum_engine: delay/gain tables moved from flip-flops to two
    block-RAM banks swapped on commit, with bank copy and a small write
    queue; frees ~4k flip-flops and the 32:1 read muxes.
    - i2s_tx MONO mode for the amplifier lines (left = right).
    - New RTL test: partial table update, write during bank copy, second
    commit — bit-exact against the model.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
2026-09-25 Docs: switch main FPGA board to Colorlight i9 + ESP32-S3
    Board comparison (Colorlight i9/i5, QMTech Artix-7, Tang Primer,
    ULX3S, MCU-only), i9 pinout section, hub schematic made board-neutral,
    BOM updated: ~$750, ~$860 with 15% reserve.
    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
    [bom.csv]
2026-09-25 Gateware: cut LUT usage (rotating I2S shift regs, serial accumulate/peaks)
    - i2s_tx: per-line rotating shift registers instead of 24:1 bit muxes;
    in MONO mode the same register serves both slots.
    - delay_sum_engine: one running accumulator and one saturator, output
    written when the last input term of each output arrives.
    - dpaa_core: a single peak meter walks the 17 microphone channels after
    each frame instead of 17 parallel abs/compare units.
    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
2026-09-25 Gateware: pipeline the serial peak meter; exact peak readback test
    The serial peak meter indexed the mic bus with pk_i*24, which synthesized
    to a multiplier plus a 17:1 mux, abs and compare in one cycle and broke
    50 MHz timing on the 45F part. Samples now shift through a copy register
    and abs/compare are split over two pipeline stages. The core test now
    checks that read-back peaks equal the running max |sample| of the
    channel (mic 1 and the calibration channel).
    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
2026-09-25 Gateware: 3-stage peak meter; ULX3S top uses plain in/out ports
    - Peak meter: separate stage for reading the stored peak, compare and
    write in the next one (was the critical path on the 45F part).
    - top_ulx3s: gp as outputs and gn as inputs instead of tri-stated inout
    buses; yosys' limited tri-state handling let the receive path be
    optimized away in the ULX3S build.
    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
2026-09-25 Docs: final resource/Fmax figures for i9, i5 and ULX3S; BOARD=i5 target
    check_all.sh results after the LUT/timing work: ~10.3k LUT, 16
    multipliers; i9 (45F) 23% LUT at 54 MHz, i5 (25F) 42% at 56 MHz,
    ULX3S (85F) 12% at 55 MHz, all above the 50 MHz clock.
    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
2026-09-25 Docs: block diagram of the whole installation
    SVG block diagram (generated by scripts/draw_block_diagram.py, PNG for
    slides): tablet/ESP32-S3 and laptop/DAPLink control, FPGA internals
    (generators, TX/RX beamforming, common I2S clock, I2S TX/RX/monitor,
    level meters), distribution board, 16 T/R elements, headphones,
    calibration probe and power. Embedded in README and architecture.md.
    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
2026-09-26 Docs: board-level wiring diagram with cable list and PMOD pin map
    New docs/hardware/wiring.md and docs/img/wiring.svg/png (generated by
    scripts/draw_wiring_diagram.py): devices A1–A22, G1/G2, BF1/BF2 with
    their connectors, cables W1–W27 (type, cores, length, signals), the
    per-pin signal map for the six PMOD ribbons, auxiliary hub connectors
    (J25 ESP32, J28 spare UART) and power-up order. Shared SVG helpers moved
    to scripts/svgdraw.py. Pinout and LPF template comments synced to the
    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
2026-09-27 Docs: purchase list — off-the-shelf boards vs. custom PCBs to order
    docs/hardware/purchase.md: exact names/quantities of ready-made boards
    and modules (Colorlight i9 + ext board, ESP32-S3-DevKitC-1, MAX98357A
    breakout, PCM5102A DAC, headphone amp, CP2102) and other bought parts;
    the four custom PCBs to fabricate (distribution board, element amp
    board, ICS-43434 micro-board with factory SMT, calibration probe) with
    sizes, order quantities and assembly method; note that Gerbers are
    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
    [bom.csv]
2026-09-27 Hardware v2: ready-made modules, one factory-assembled custom board
    Per the goal of maximum off-the-shelf boards and minimum hand assembly:
    - Elements now use a ready MAX98357A module and a ready round ICS-43434
    microphone module on Dupont F-F wires; the custom element amplifier
    board and the SMT micro-board are dropped.
    - Holder redesigned as a 40x60 mm tile: speaker in a sealed volume
    below, a through-hole seat with front lip for the round mic module
    above (mic_d parameter, measure the module); amplifier module is
    zip-tied to the back panel. MIC_OFFSET updated (29.8 mm above the
    speaker centre).
    - Distribution board is the only custom PCB, to be factory-assembled:
    per-load cl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
    [back_round32.stl, back_square32.stl, bom.csv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]
2026-09-27 Replace Dayton CE32A-8 with a common 28 mm 8 Ohm 2 W speaker
    The element holder is now parametric in the speaker (spk_table: frame
    diameter, depth, rim thickness, magnet), with presets rd28 (default,
    common 28 mm micro speaker), rd36 (36 mm mylar 1 W), rd32 (CE32A-8)
    and sq32 (Visaton). Cavity, horn, pocket and back-plate posts follow
    the chosen size. STL and renders rebuilt; BOM, purchase list, budget
    (~630 $, ~725 $ with reserve) and diagrams updated.
    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
    [back_rd28.stl, back_rd32.stl, back_rd36.stl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]
2026-09-27 Support 15x24 mm oval speaker in the element holder
    Speaker outline is now generic (round, square, oval stadium); the
    table gains height and cavity depth. Preset ov1524 (8 Ohm 0.8/1 W,
    3.5 mm thick, 50 mm leads) uses a 10 mm cavity so the short leads
    reach the amplifier, and four back-cover posts near the ends of the
    oval clear the magnet and the cable hole. STL and renders added,
    docs and BOM list it as an equal alternative to the 28 mm speaker.
    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
    [back_ov1524.stl, back_rd28.stl, back_rd36.stl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]
2026-09-27 Add full block diagram of the whole installation
    New scripts/draw_full_diagram.py renders docs/img/full_diagram.svg/png
    with nothing merged: all 16 elements with their modules and cables,
    all 13 buffers of the distribution board with taps to connector pins,
    every gateware block with the register bus, the power chain with
    fuses and regulators, all connectors and cables W1-W28, plus a table
    decoding every abbreviation and reference designator. Linked from
    architecture.md and README. Also fixes the regulator designator in
    wiring.md (U20, not U10).
    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
    [draw_full_diagram.py]
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2026-10-22 Распределительная плата: порт Ethernet (P1 -> MagJack), плата 100x180, исправлена нумерация вилок IDC
    - J19 = гребёнка P1 платы расширения (третий прямой шлейф IDC 2x15), J29 = RJ45 MagJack
    UDE RB1-125B8G1A (1000BASE-T, трансформаторы и терминация Боба Смита внутри, общий вывод
    и экран — на отдельную цепь CHASSIS: полигон под гнездом на обоих слоях, к земле через
    C306 1 нФ 2 кВ || R306 1 МОм); центральный отвод — C301 100 нФ, R301 0 Ом (DNP) к 3,3 В.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
